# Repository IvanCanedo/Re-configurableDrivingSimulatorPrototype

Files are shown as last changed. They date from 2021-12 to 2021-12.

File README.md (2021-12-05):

# Re-configurableDrivingSimulatorPrototype
All files for a Re-configurable Driving Simulator Prototype

Requirements:

Windows 10 20H2

Solidworks Premium 2019 SP4.0

MATLAB 2018b 9.5.0.944444

LabVIEW 2019 19.0f2

KiCad 5.1.10

-To run MATLAB/Simulink simulation-

First open and run

/MATLAB/cinematica_inversa.m

then open and run:

/MATLAB/simulacion/platafomra_esfera.slx

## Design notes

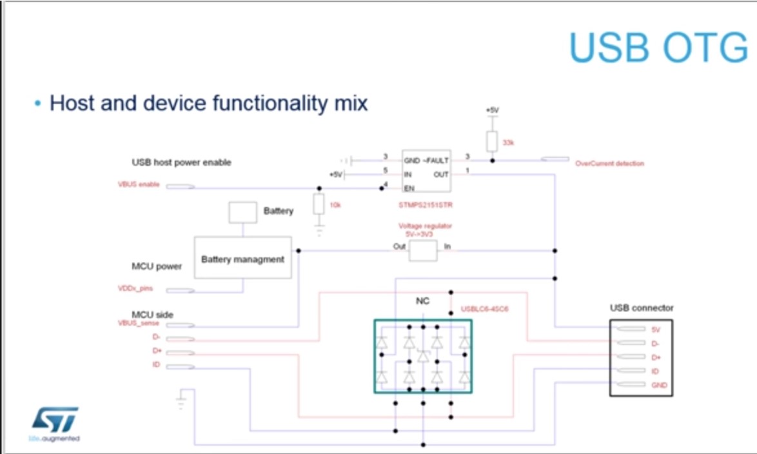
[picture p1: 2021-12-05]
KiCad/Nodo CAN/USB_OTG_ESD.jpg

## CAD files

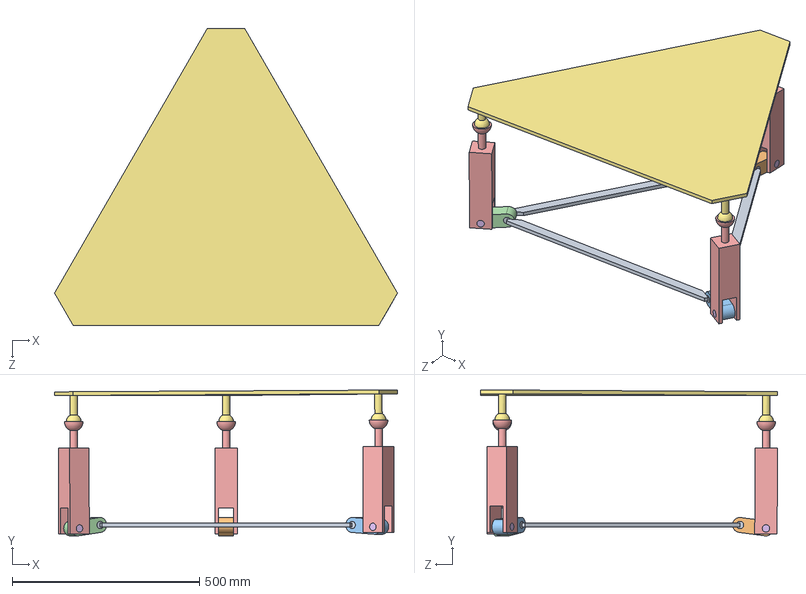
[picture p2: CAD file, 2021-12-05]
MATLAB/simulacion/platafomra_esfera.SLDASM
916.1 x 389.5 x 793.3 mm
base
viela
viela2
viela3
pilar x 3
pin inferior x 3
plataforma_soporte

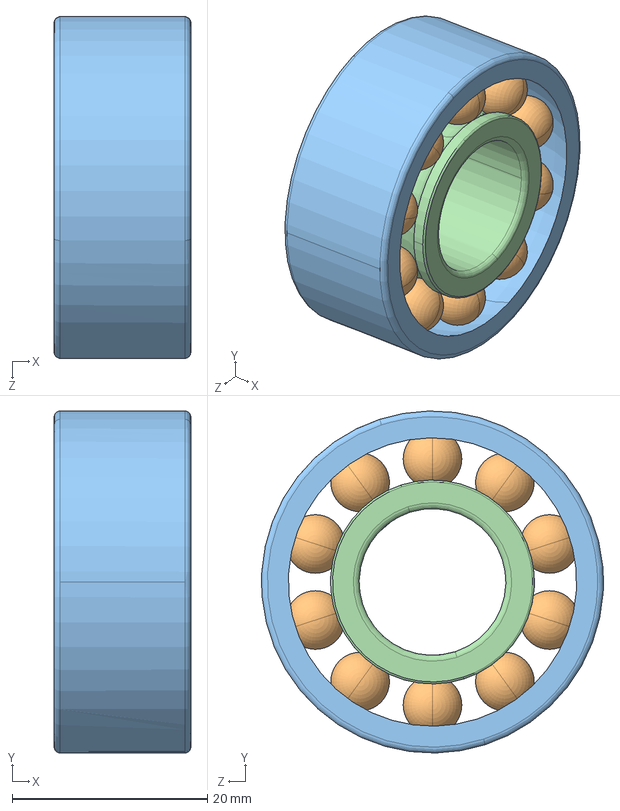
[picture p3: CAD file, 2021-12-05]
Solidworks/Full-Scale/PARTserver0202011032242190391701010e898ce/2202_ETN9.sldasm
14.0 x 35.0 x 35.0 mm
2202_ETN9_3 x 10
2202_ETN9_14 x 10
2202_ETN9_29
2202_ETN9_31

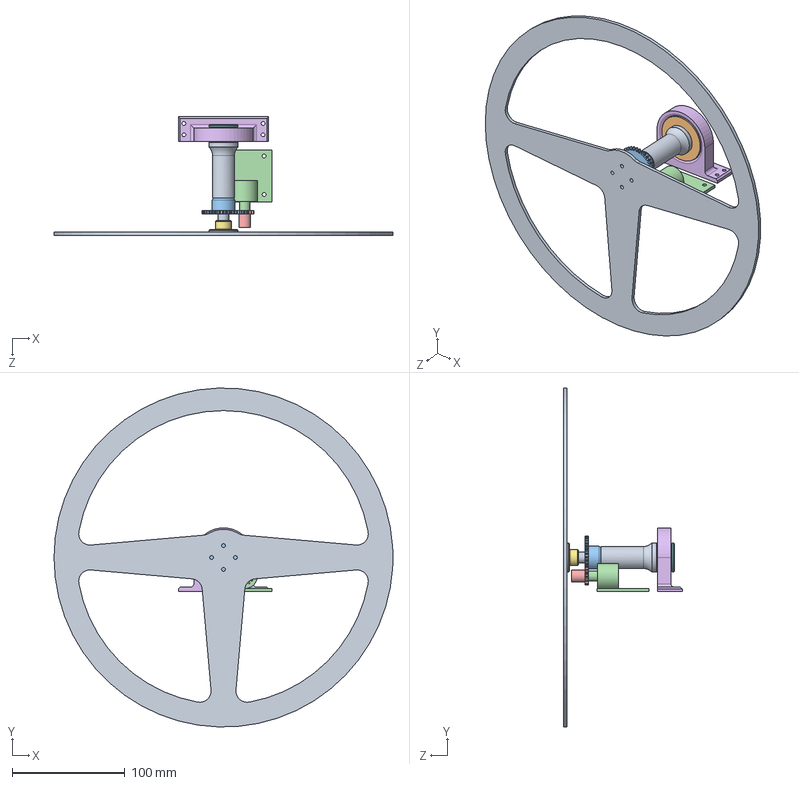
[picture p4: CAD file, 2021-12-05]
Solidworks/Vehicle control devices/volante.SLDASM
300.0 x 299.9 x 104.9 mm
eje
rodamiento
gear36
pot
gear14
abrazadera
cople volante
tapa rodamiento
SteeringWheel

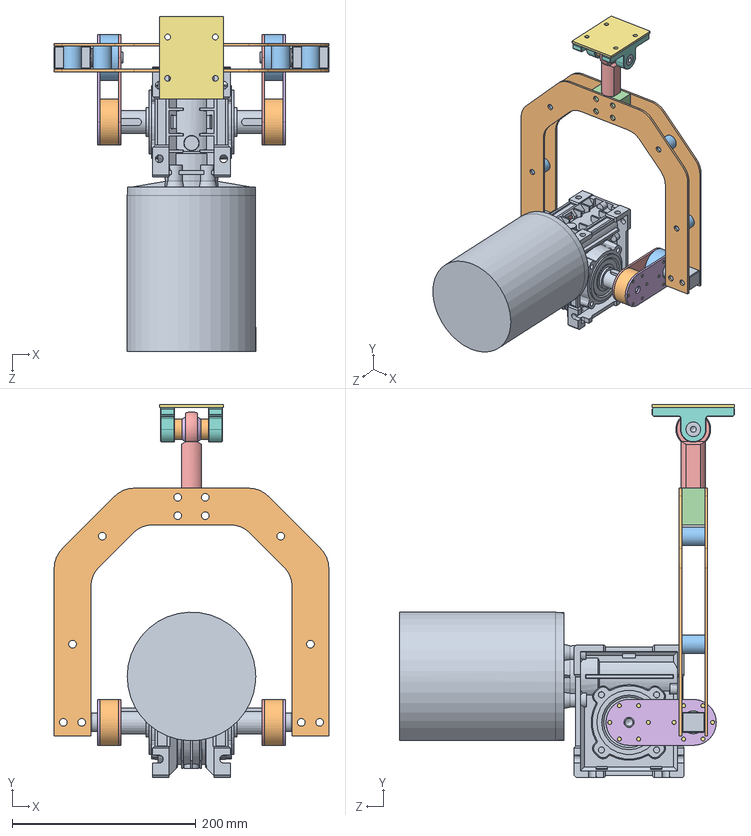
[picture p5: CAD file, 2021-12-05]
Solidworks/Full-Scale/motor con viela.SLDASM
299.0 x 406.0 x 365.0 mm
reductor con motor
cople flecha x 2
cople rodamiento x 2
rodameitno falso x 2
placa manivela x 2
placa manivela 2 x 2
tornillo falso x 24
anillo manivela x 2
pin de manivela x 2
arco x 2
virlo x 4
bloque
rotula
esfera
placa superior
soporte superior x 2
pin superior
virlo superior x 2

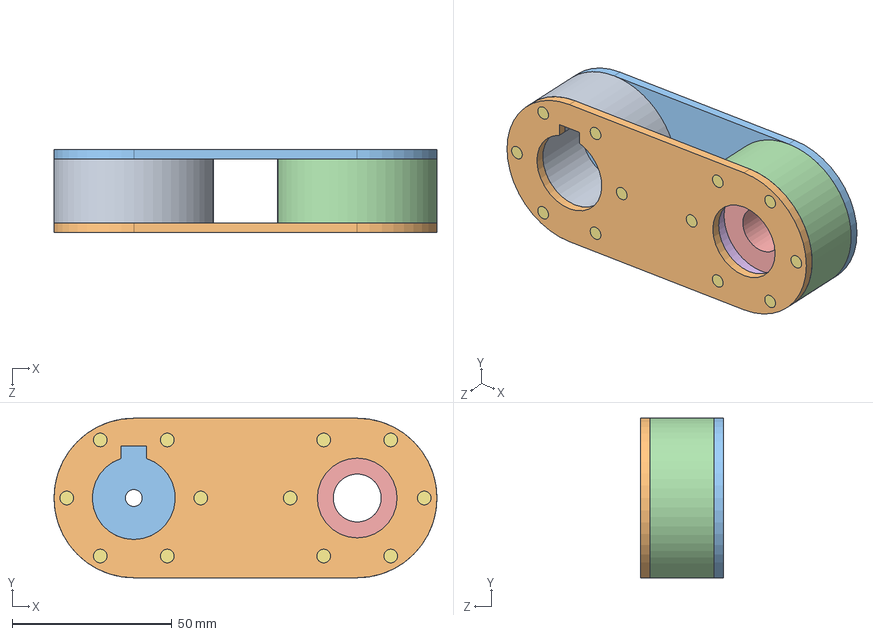
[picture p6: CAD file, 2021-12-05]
Solidworks/Finite Element/manivela 1.SLDASM
120.0 x 50.0 x 26.0 mm
cople flecha
placa manivela
placa manivela 2
cople rodamiento
rodameitno falso
anillo manivela
tornillo falso x 12

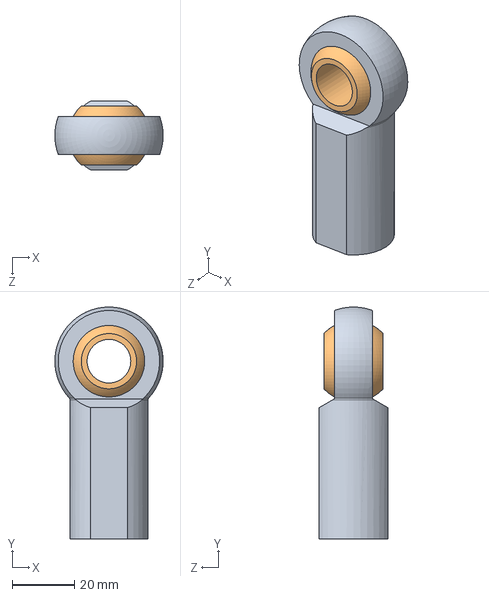
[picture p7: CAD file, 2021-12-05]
Solidworks/Full-Scale/Rotula de esfera.SLDASM
34.7 x 74.4 x 22.0 mm
rotula
esfera

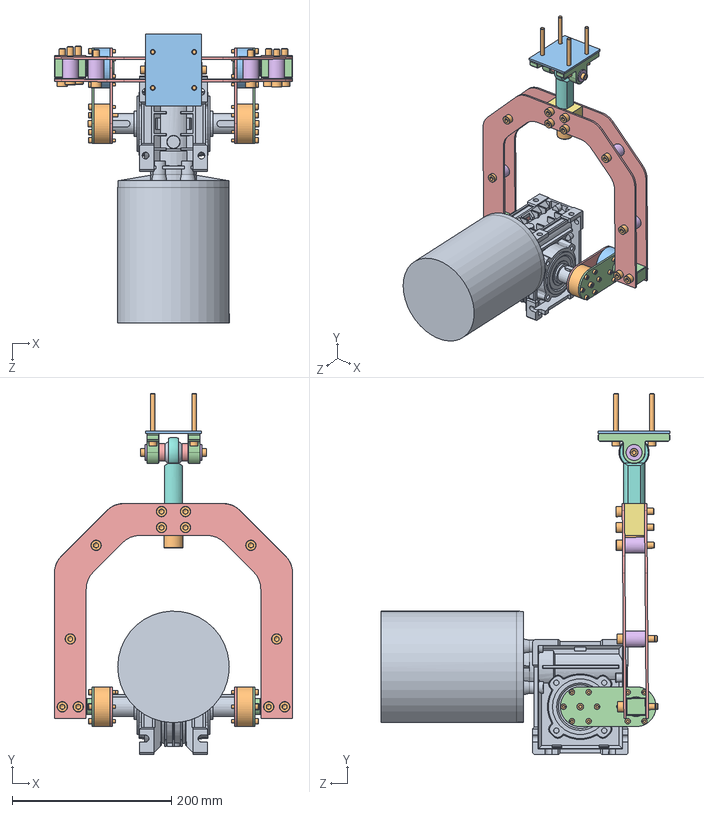
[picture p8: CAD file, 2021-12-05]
Solidworks/Full-Scale/pata con todo.SLDASM
299.0 x 453.0 x 362.5 mm
reductor con motor
cople flecha x 2
cople rodamiento x 2
placa manivela 2 x 2
placa manivela x 2
2202_ETN9_3 x 20
2202_ETN9_14 x 20
2202_ETN9_29 x 2
2202_ETN9_31 x 2
socket head cap screw_iso x 45
anillo manivela x 2
pin de manivela x 2
arco x 2
virlo x 4
bloque
rotula
esfera
pin superior
placa superior
soporte superior x 2
virlo superior x 2
plain washer 10669 type nl_iso x 2

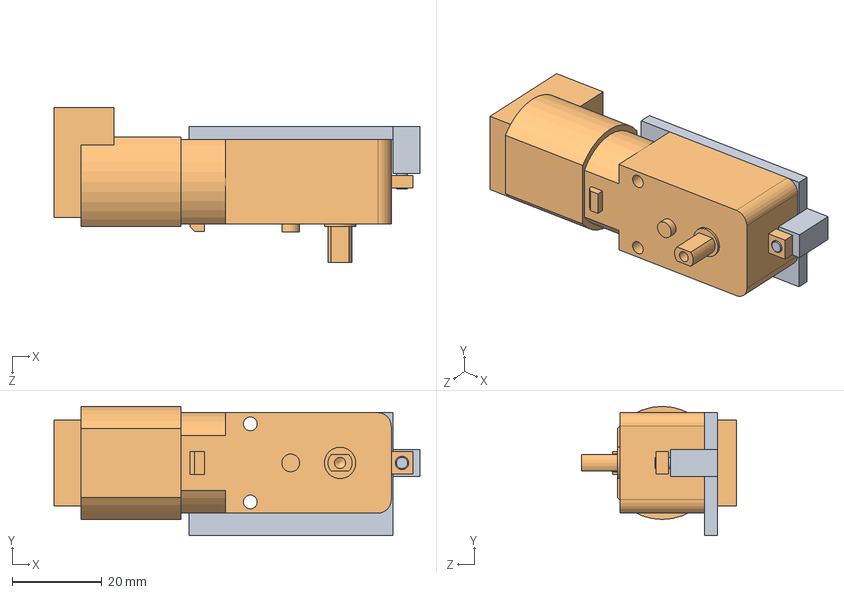
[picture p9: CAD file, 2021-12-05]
Solidworks/Scale/motor con base.SLDASM
81.6 x 28.8 x 34.6 mm
base motor
motor

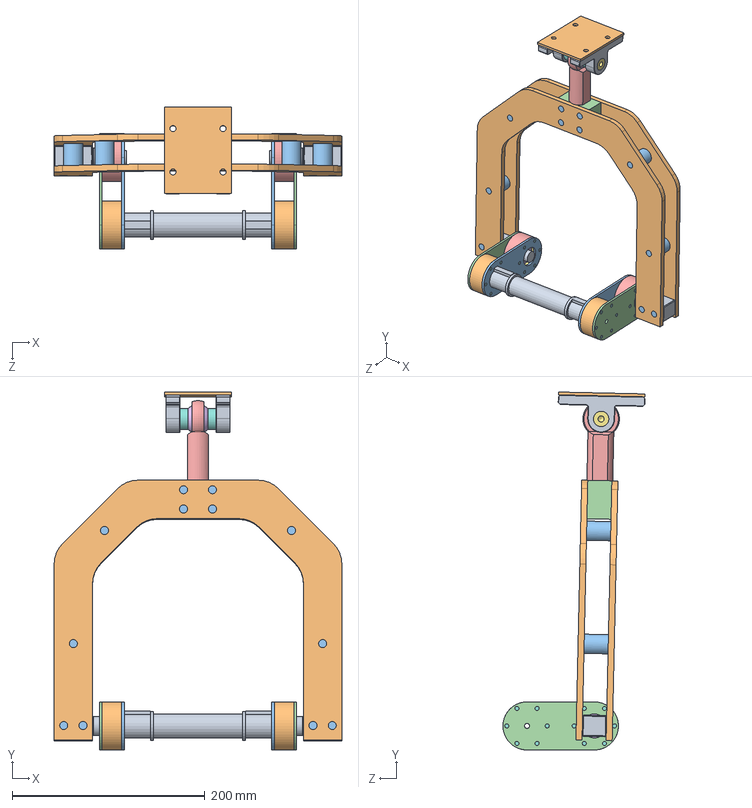
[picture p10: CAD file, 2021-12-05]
Solidworks/Finite Element/pata 1.SLDASM
299.0 x 371.9 x 147.6 mm
flecha motor
cople flecha x 2
placa manivela x 2
placa manivela 2 x 2
cople rodamiento x 2
rodameitno falso x 2
anillo manivela x 2
tornillo falso x 24
pin de manivela x 2
arco x 2
virlo x 4
bloque
rotula
esfera
pin superior
virlo superior x 2
soporte superior x 2
placa superior
tronillo falso m8 x 12

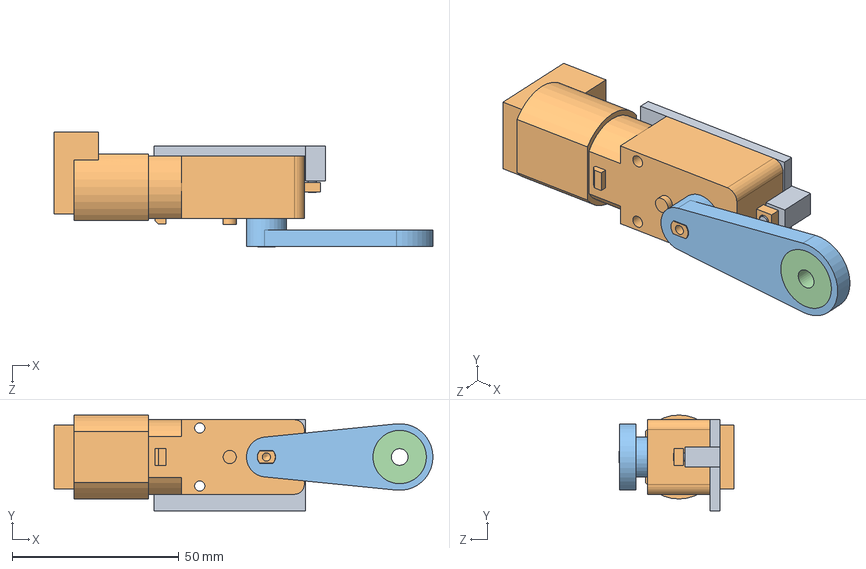
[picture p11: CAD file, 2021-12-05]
Solidworks/Scale/motor con base y manivela.SLDASM
113.7 x 28.8 x 34.6 mm
base motor
motor
manivela
rodamiento

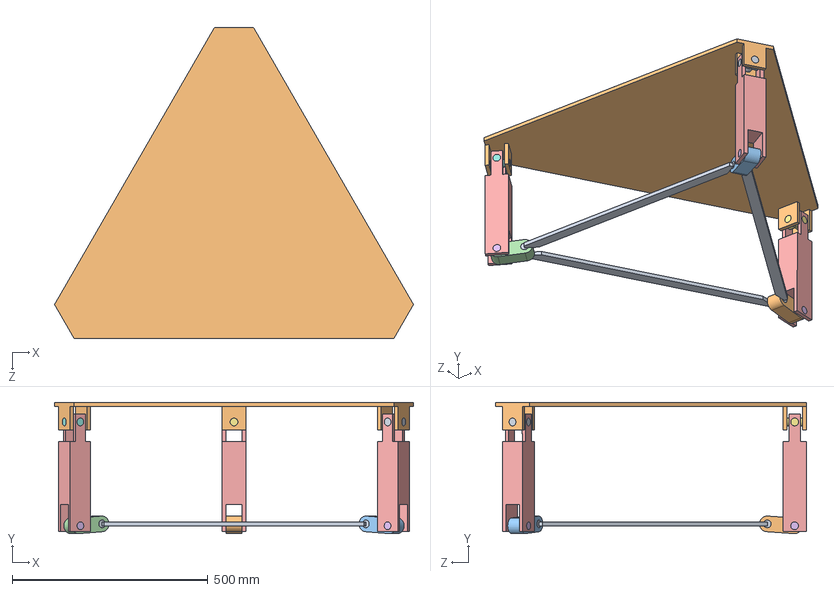
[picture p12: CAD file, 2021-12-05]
MATLAB/simulacion/base_viela.SLDASM
916.0 x 335.0 x 793.3 mm
base
viela
viela2
viela3
pilar x 3
pin inferior x 3
cruz
cruz2
cruz3
plataforma_soporte

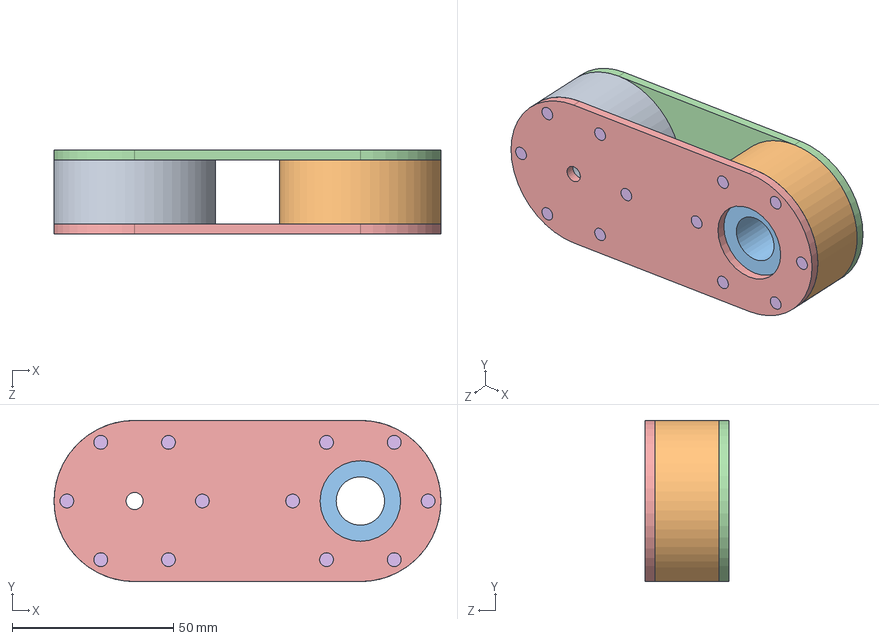
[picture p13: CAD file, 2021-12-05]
Solidworks/Full-Scale/manivela.SLDASM
120.0 x 50.0 x 26.0 mm
cople flecha
cople rodamiento
rodameitno falso
placa manivela
placa manivela 2
tornillo falso x 12
anillo manivela

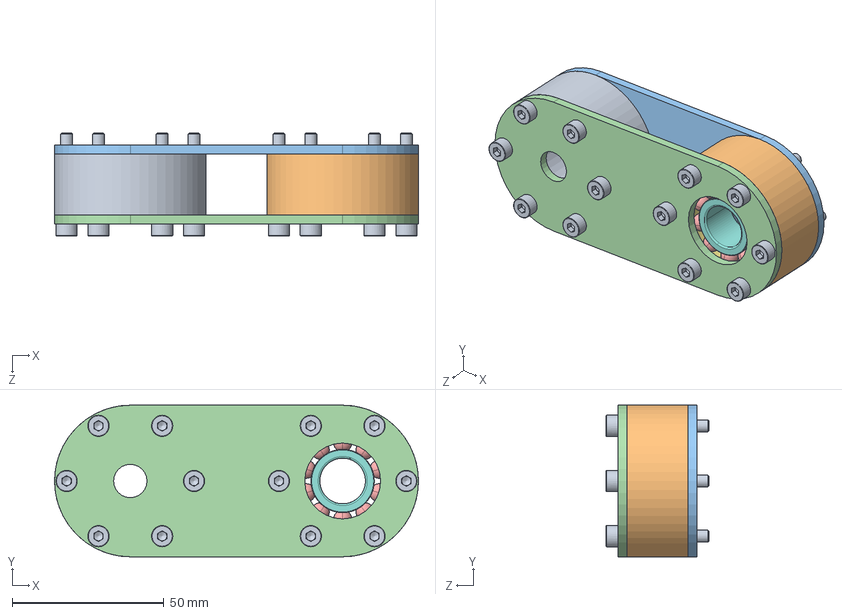
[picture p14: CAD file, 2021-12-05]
Solidworks/Full-Scale/manivela con rodamiento.SLDASM
120.0 x 50.0 x 34.0 mm
cople flecha
cople rodamiento
placa manivela
placa manivela 2
2202_ETN9_3 x 10
2202_ETN9_14 x 10
2202_ETN9_29
2202_ETN9_31
socket head cap screw_iso x 12
anillo manivela

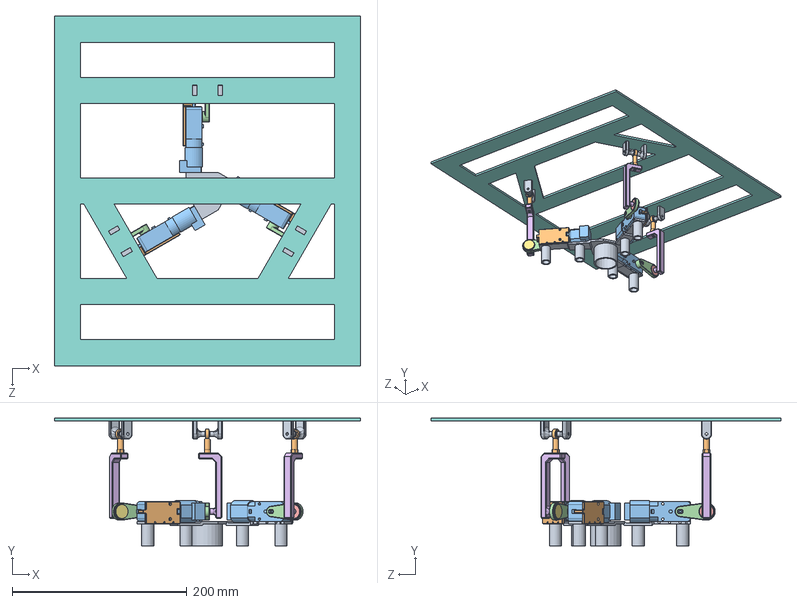
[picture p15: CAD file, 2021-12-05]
Solidworks/Scale/Plataforma.SLDASM
350.0 x 145.9 x 400.0 mm
base plataforma
base motor x 3
motor x 3
manivela x 3
rodamiento x 3
puente2 x 3
tapa rodamiento x 3
plataforma superior
soporte superior x 6
rotula de esfera x 3

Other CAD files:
Solidworks/Finite Element/manivela 2.SLDASM
Solidworks/Full-Scale/manivela derecha.SLDASM
Solidworks/Full-Scale/plataforma.SLDASM
Solidworks/Scale/Ensamblaje1.SLDASM
MATLAB/simulacion/base.SLDPRT
MATLAB/simulacion/base_Predeterminado_sldprt.STEP
MATLAB/simulacion/pilar.SLDPRT
MATLAB/simulacion/pilar_Predeterminado_sldprt.STEP
MATLAB/simulacion/pin inferior.SLDPRT
MATLAB/simulacion/pin inferior_Predeterminado_sldprt.STEP
MATLAB/simulacion/plataforma.SLDPRT
MATLAB/simulacion/plataforma_Predeterminado_sldprt.STEP
MATLAB/simulacion/plataforma_soporte.SLDPRT
MATLAB/simulacion/plataforma_soporte_Predeterminado_sldprt.STEP
MATLAB/simulacion/soporte sup.SLDPRT
MATLAB/simulacion/soporte sup_Predeterminado_sldprt.STEP
MATLAB/simulacion/viela.SLDPRT
MATLAB/simulacion/viela2.SLDPRT
MATLAB/simulacion/viela2_Predeterminado_sldprt.STEP
MATLAB/simulacion/viela3.SLDPRT
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

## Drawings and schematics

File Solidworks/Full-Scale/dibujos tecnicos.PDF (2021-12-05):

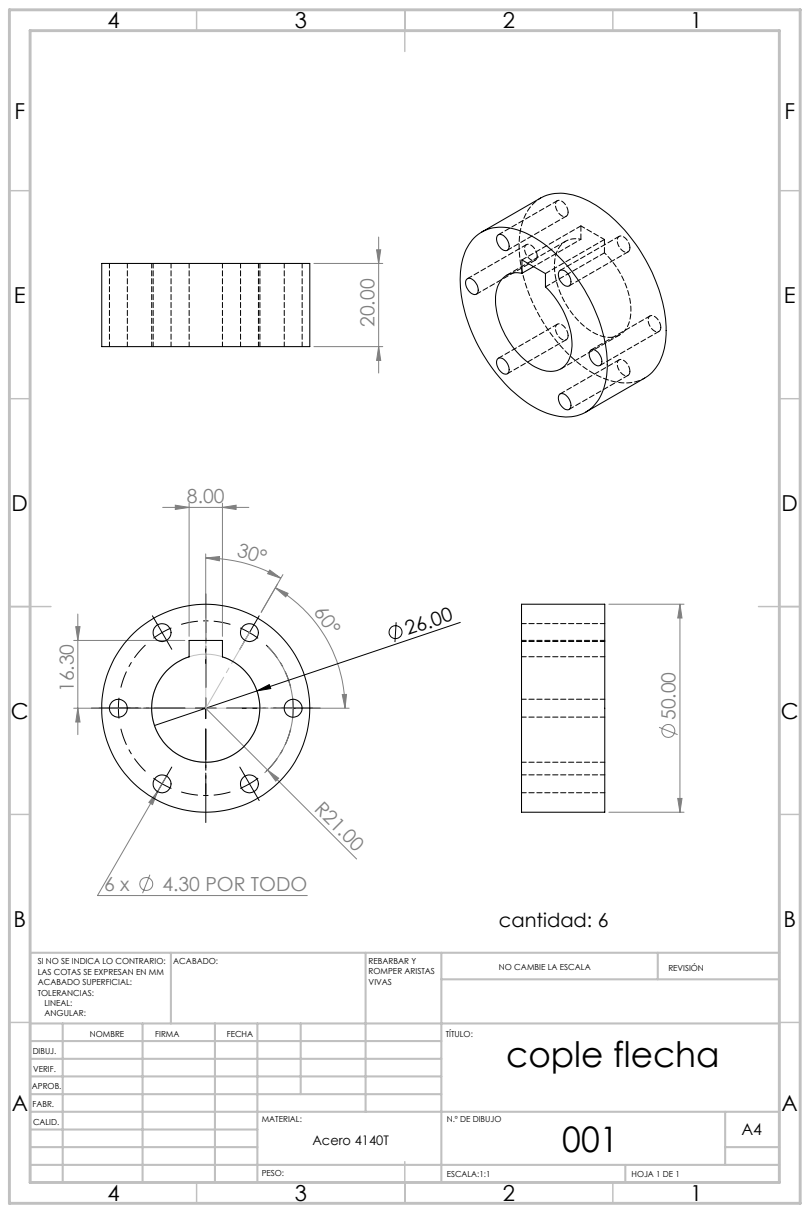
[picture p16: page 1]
4.30 POR TODO; ACABADO:; REBARBAR Y; ROMPER ARISTAS; NO CAMBIE LA ESCALA; REVISIÓN; ESCALA:1:1; HOJA 1 DE 1; cantidad: 6

SI NO SE INDICA LO CONTRARIO:
LAS COTAS SE EXPRESAN EN MM
ACABADO SUPERFICIAL:
TOLERANCIAS:
LINEAL:
ANGULAR:

NOMBRE | FIRMA | FECHA | | | | TÍTULO: cople flecha

DIBUJ.
VERIF.
APROB.
FABR.
CALID. | | | | MATERIAL: Acero 4140T | N.º DE DIBUJO | A4

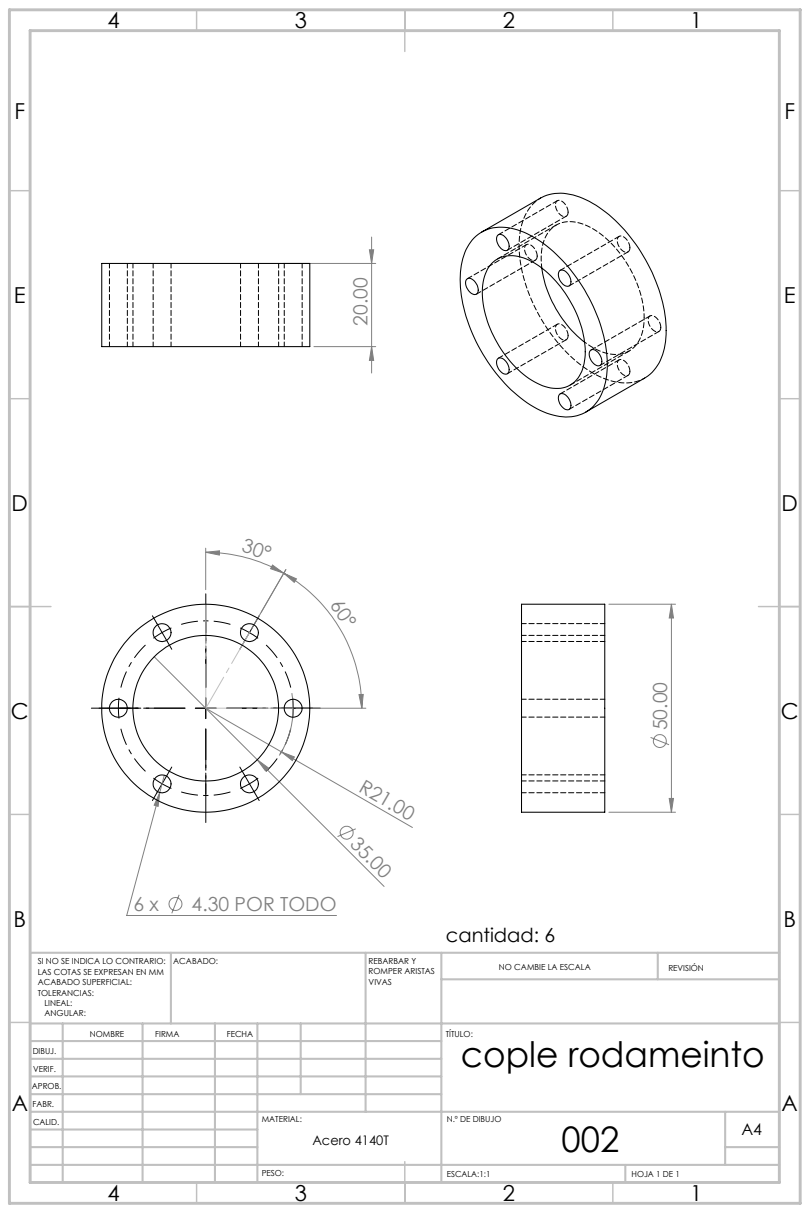
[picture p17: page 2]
4.30 POR TODO; ACABADO:; REBARBAR Y; ROMPER ARISTAS; NO CAMBIE LA ESCALA; REVISIÓN; cantidad: 6

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

NOMBRE | FIRMA | FECHA | TÍTULO: cople rodameinto

DIBUJ.
VERIF.
APROB.
FABR.

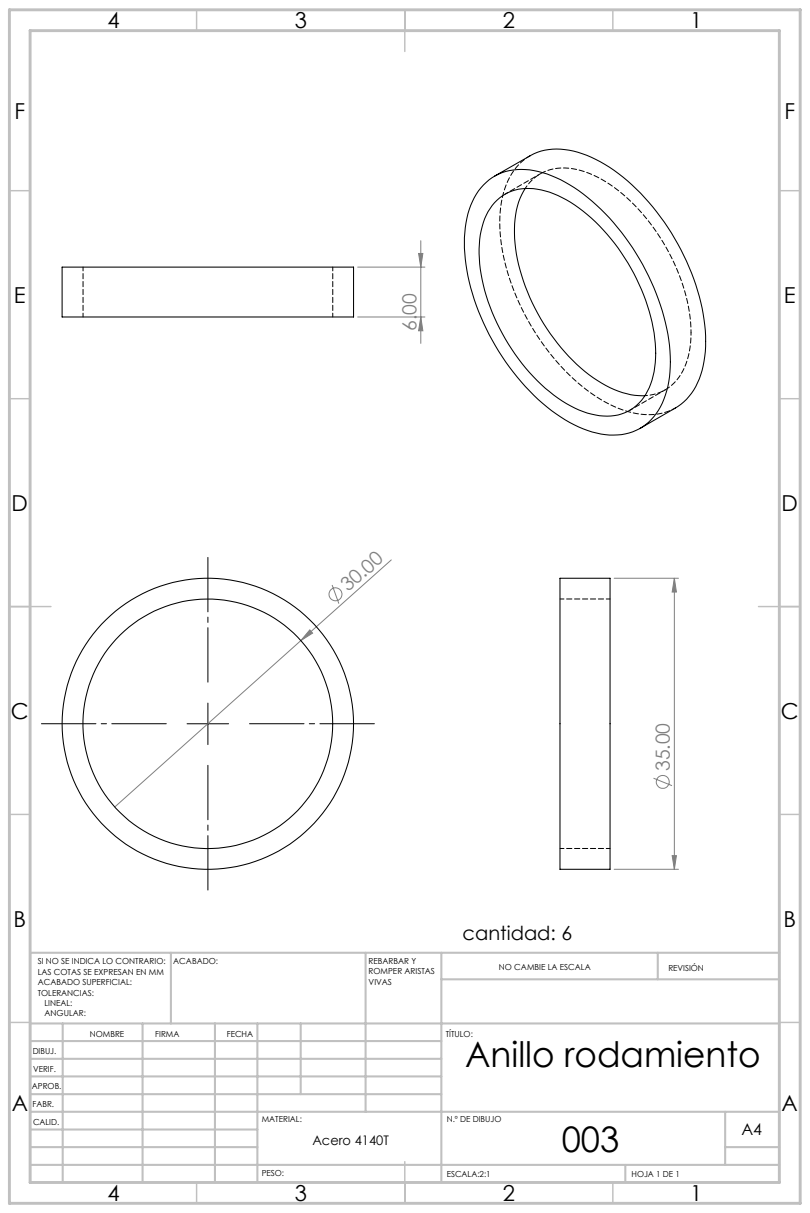
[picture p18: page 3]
cantidad: 6; ACABADO:; REBARBAR Y; ROMPER ARISTAS; NO CAMBIE LA ESCALA; REVISIÓN; ESCALA:2:1; HOJA 1 DE 1

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

NOMBRE | FIRMA | FECHA | TÍTULO: Anillo rodamiento

DIBUJ.
VERIF.
APROB.
FABR.

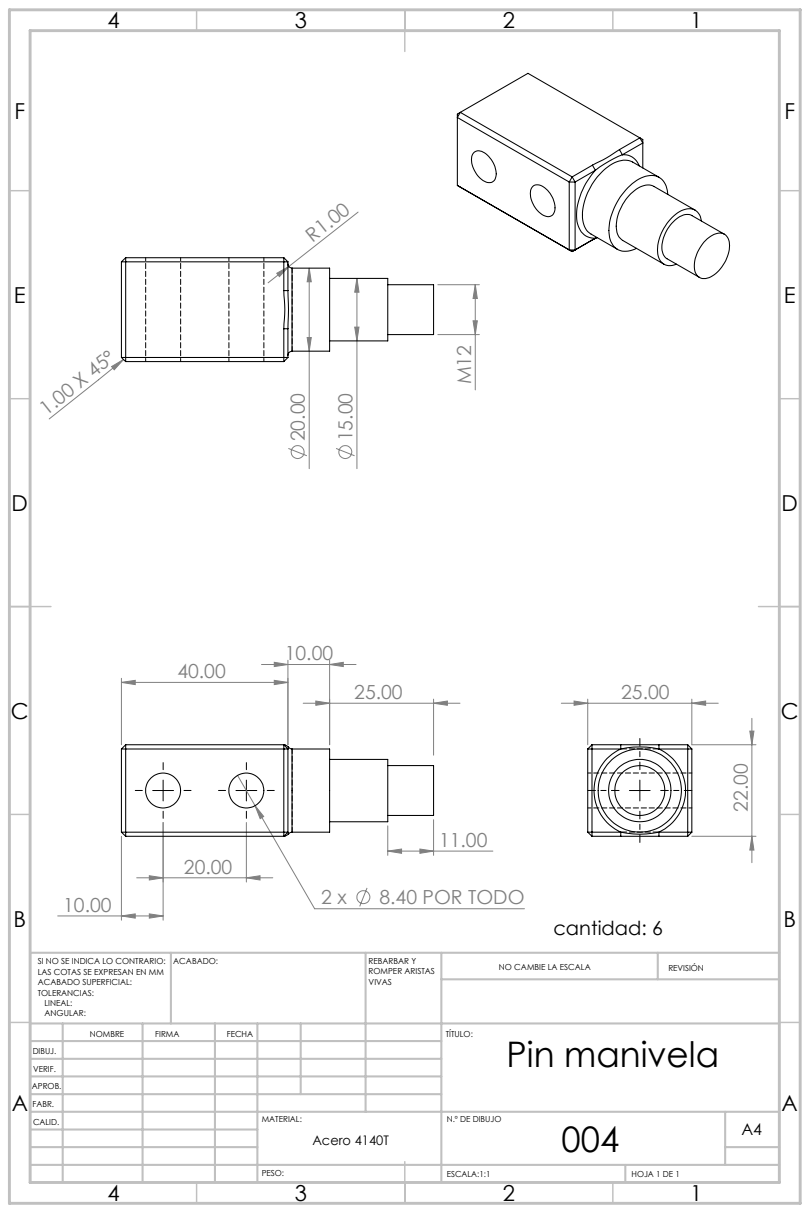
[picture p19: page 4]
8.40 POR TODO; cantidad: 6; ACABADO:; REBARBAR Y; ROMPER ARISTAS; NO CAMBIE LA ESCALA; REVISIÓN

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

NOMBRE | FIRMA | FECHA | TÍTULO: Pin manivela

DIBUJ.
VERIF.
APROB.
FABR.

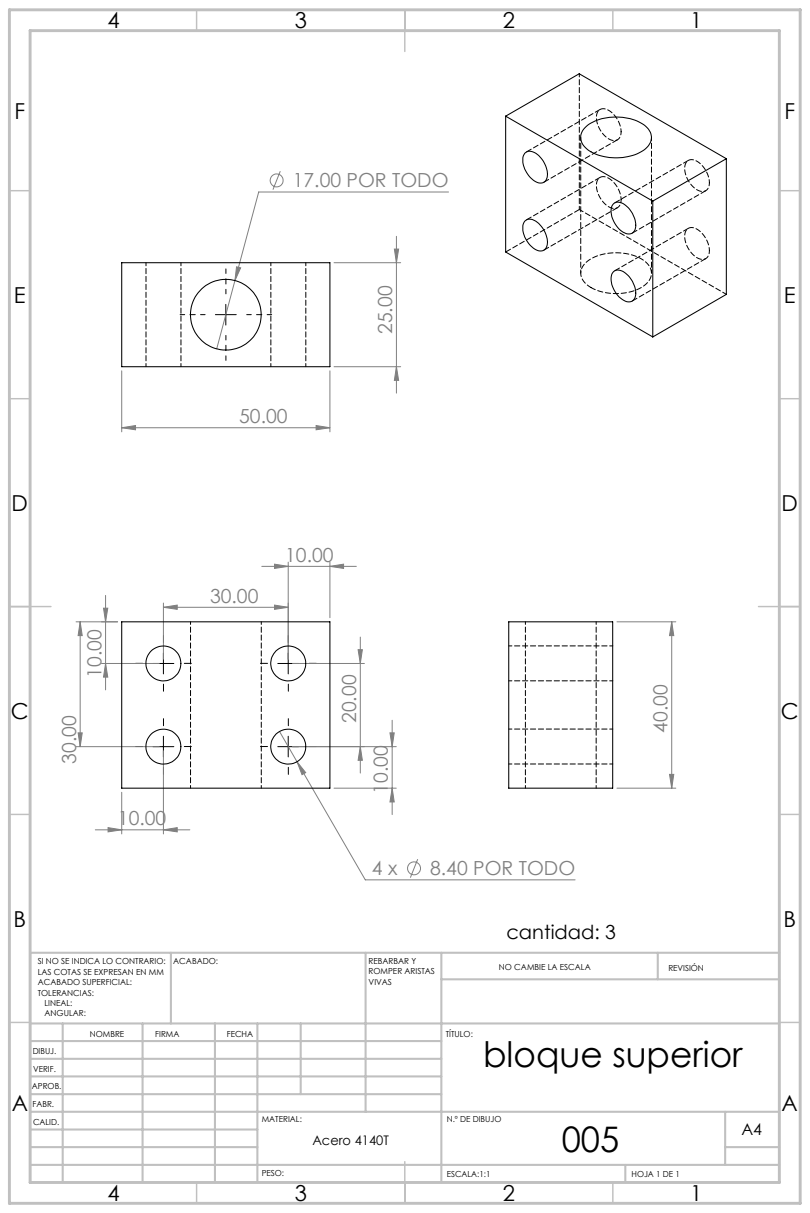
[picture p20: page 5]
8.40 POR TODO 10.00; 17.00 POR TODO 25.00; cantidad: 3; ACABADO:; REBARBAR Y; ROMPER ARISTAS; NO CAMBIE LA ESCALA; REVISIÓN

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

NOMBRE | FIRMA | FECHA | TÍTULO: bloque superior

DIBUJ.
VERIF.
APROB.
FABR.

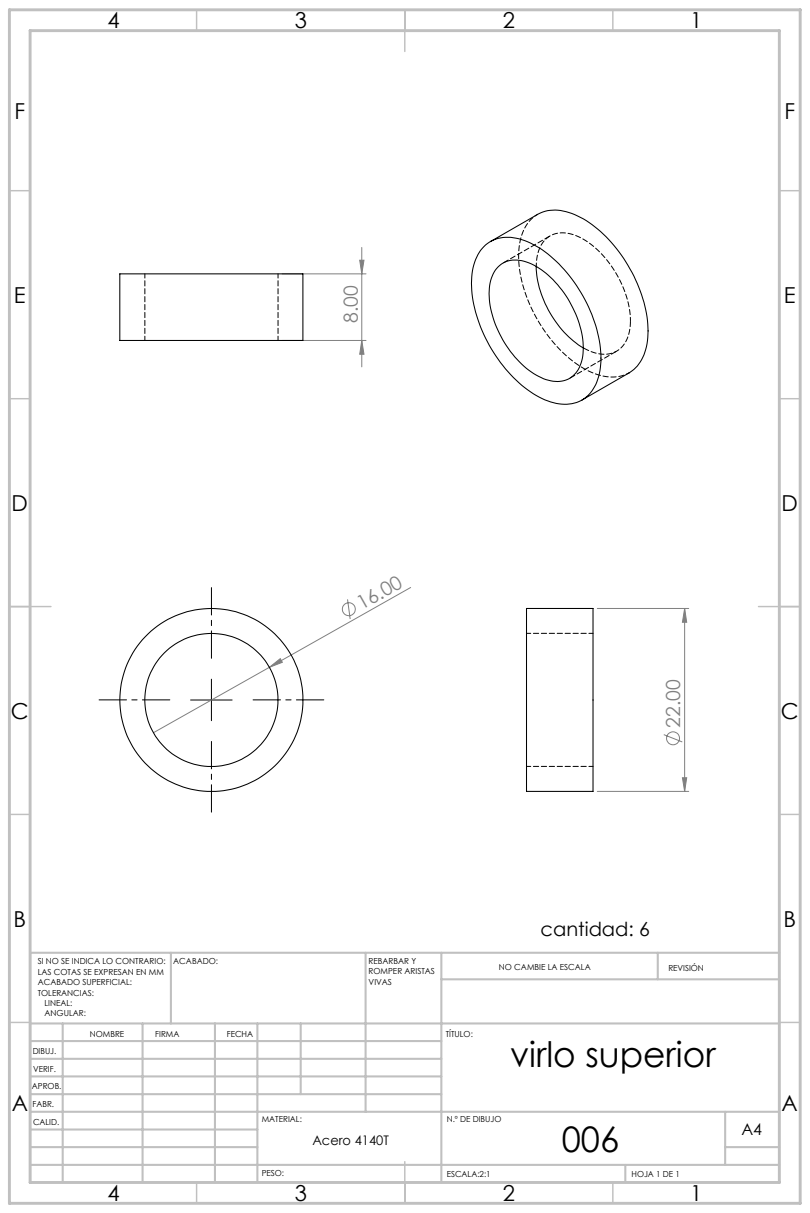
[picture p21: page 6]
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

NOMBRE | FIRMA | FECHA | TÍTULO: virlo superior

DIBUJ.
VERIF.
APROB.
FABR.

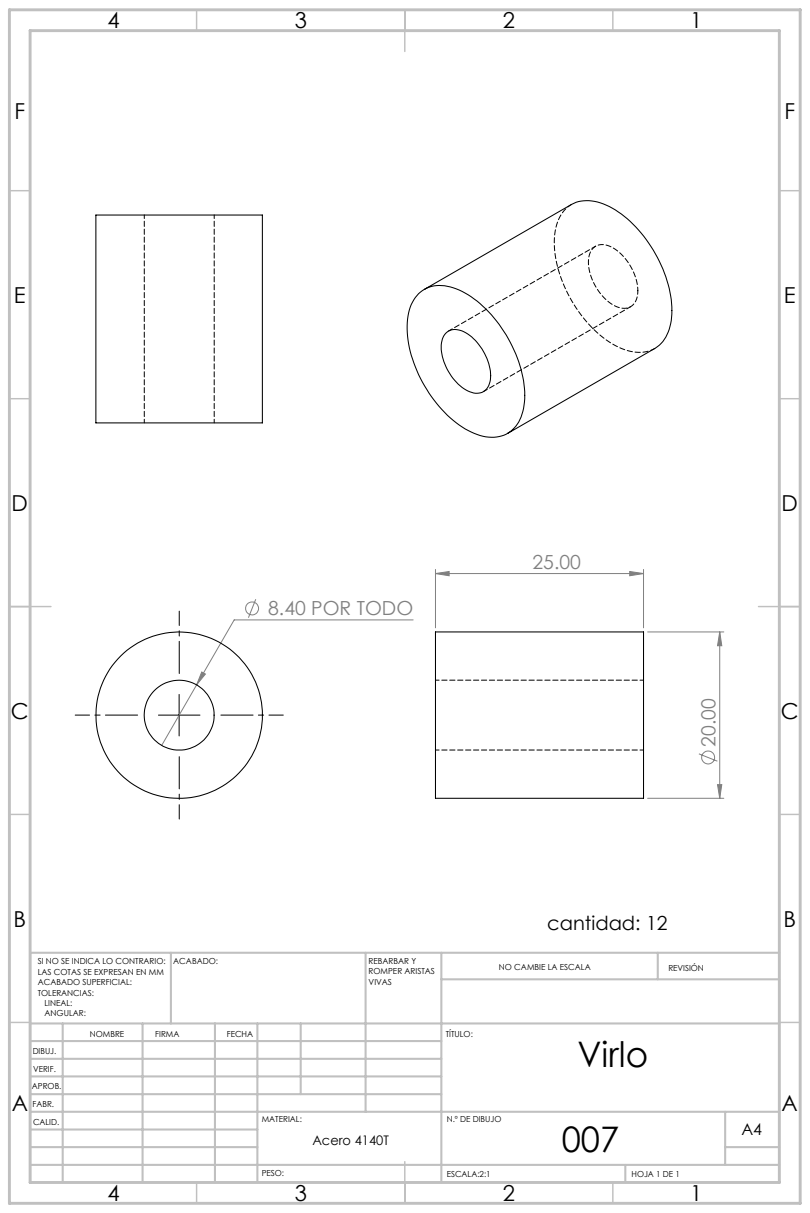
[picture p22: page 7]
8.40 POR TODO; cantidad: 12; ACABADO:; REBARBAR Y; ROMPER ARISTAS; NO CAMBIE LA ESCALA; REVISIÓN; ESCALA:2:1; HOJA 1 DE 1

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

NOMBRE | FIRMA | FECHA | TÍTULO: Virlo

DIBUJ.
VERIF.
APROB.
FABR.

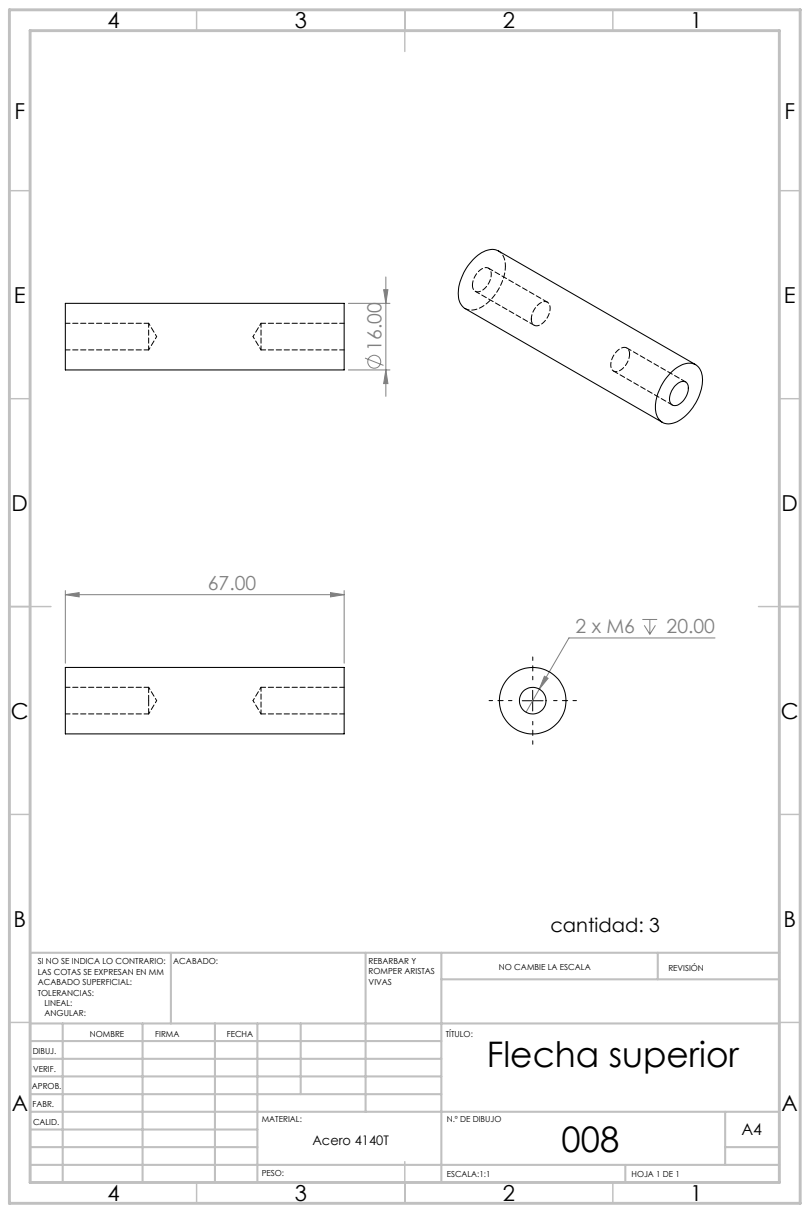
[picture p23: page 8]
cantidad: 3; ACABADO:; REBARBAR Y; ROMPER ARISTAS; NO CAMBIE LA ESCALA; REVISIÓN

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

NOMBRE | FIRMA | FECHA | TÍTULO: Flecha superior

DIBUJ.
VERIF.
APROB.
FABR.

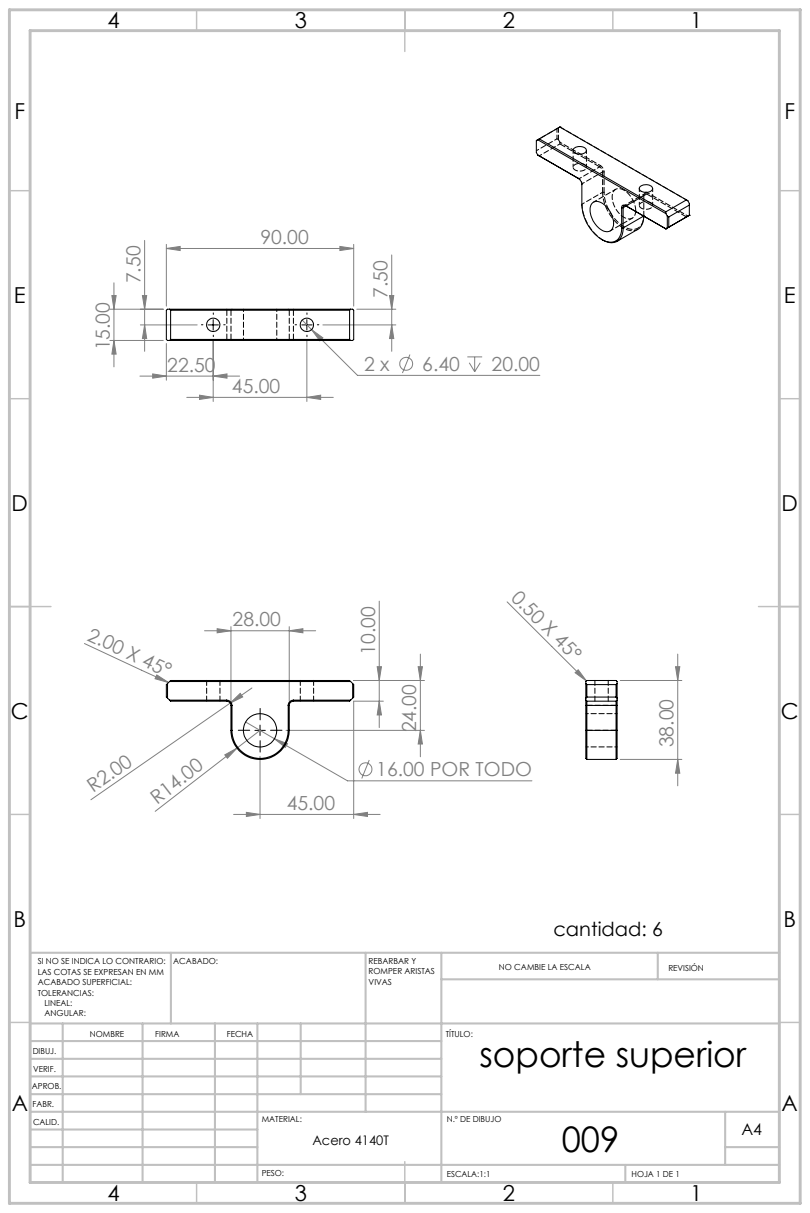
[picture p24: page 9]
16.00 POR TODO; cantidad: 6; ACABADO:; REBARBAR Y; ROMPER ARISTAS; NO CAMBIE LA ESCALA; REVISIÓN

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

NOMBRE | FIRMA | FECHA | TÍTULO: soporte superior

DIBUJ.
VERIF.
APROB.
FABR.

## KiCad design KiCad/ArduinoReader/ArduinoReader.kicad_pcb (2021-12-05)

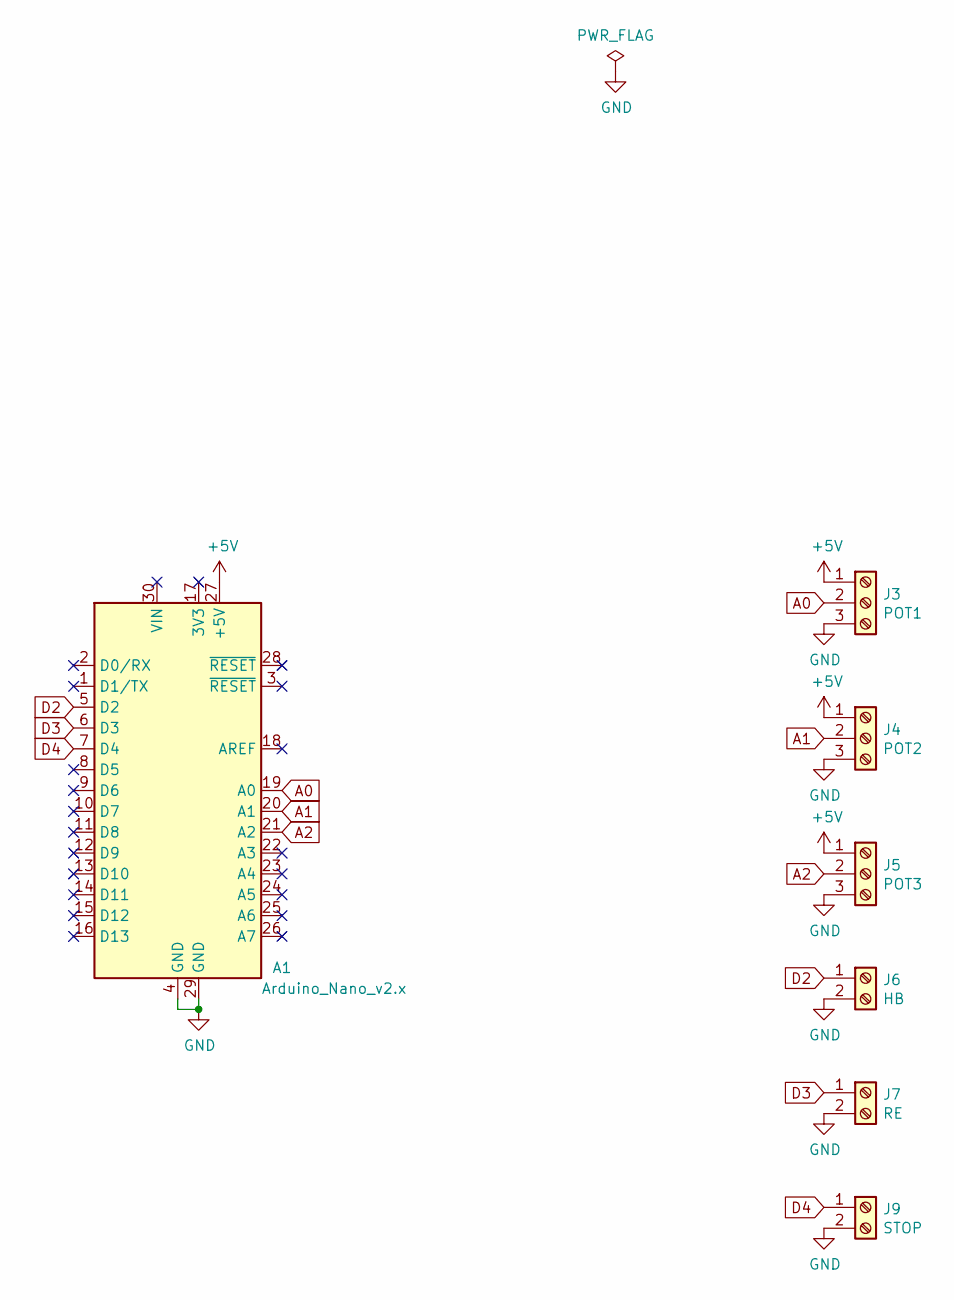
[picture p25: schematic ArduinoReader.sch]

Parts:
A1: Arduino_Nano_v2.x; Arduino_Nano
J3: POT1; TerminalBlock_Phoenix_MKDS-1,5-3_1x03_P5.00mm_Horizontal
J4: POT2; TerminalBlock_Phoenix_MKDS-1,5-3_1x03_P5.00mm_Horizontal
J5: POT3; TerminalBlock_Phoenix_MKDS-1,5-3_1x03_P5.00mm_Horizontal
J6: HB; TerminalBlock_Phoenix_MKDS-1,5-2_1x02_P5.00mm_Horizontal
J7: RE; TerminalBlock_Phoenix_MKDS-1,5-2_1x02_P5.00mm_Horizontal
J9: STOP; TerminalBlock_Phoenix_MKDS-1,5-2_1x02_P5.00mm_Horizontal

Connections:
+5V: A1.27 (+5V), J3.1, J4.1, J5.1
A0: A1.19 (A0), J3.2
A1: A1.20 (A1), J4.2
A2: A1.21 (A2), J5.2
D2: A1.5 (D2), J6.1
D3: A1.6 (D3), J7.1
D4: A1.7 (D4), J9.1
GND: A1.4 (GND), A1.29 (GND), J3.3, J4.3, J5.3, J6.2, J7.2, J9.2

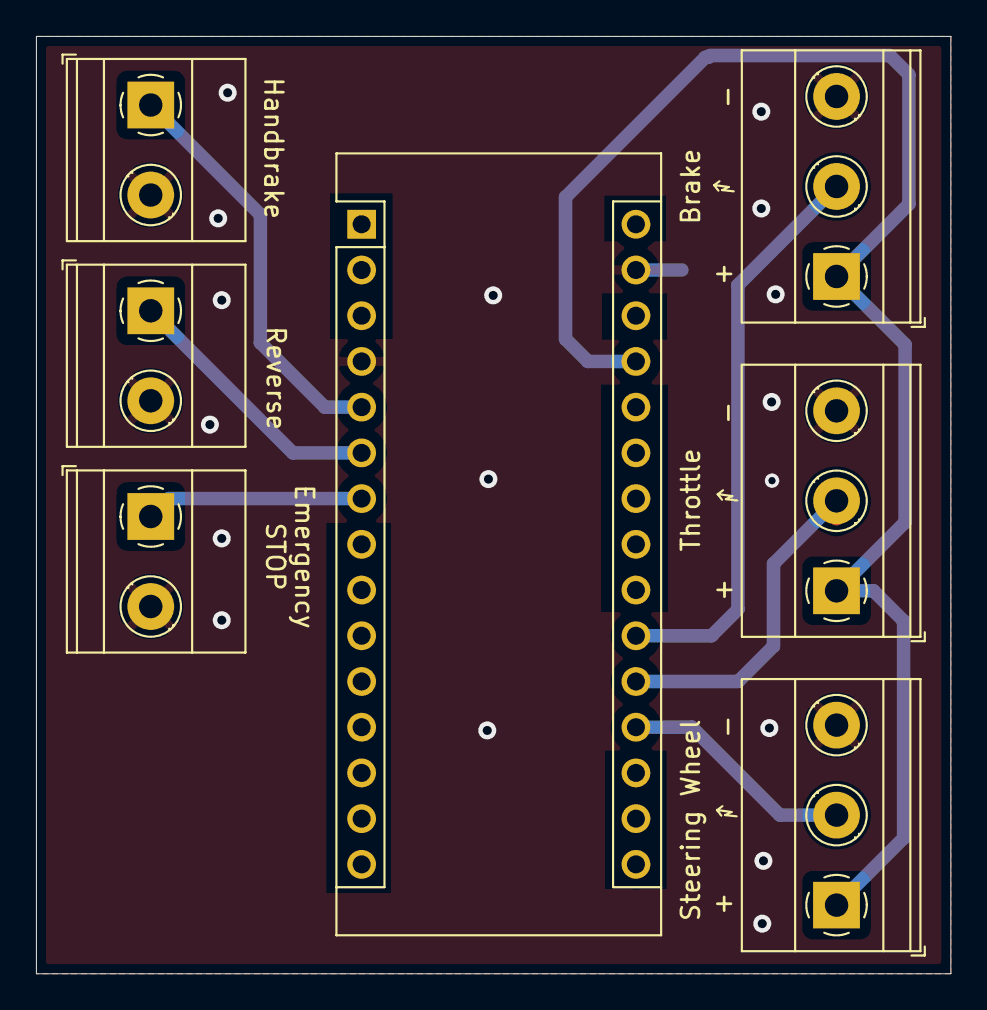
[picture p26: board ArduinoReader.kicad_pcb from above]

Board: 2 copper layers, 50.8 x 52.1 mm, 7 parts (0 on the bottom side), 8 nets.

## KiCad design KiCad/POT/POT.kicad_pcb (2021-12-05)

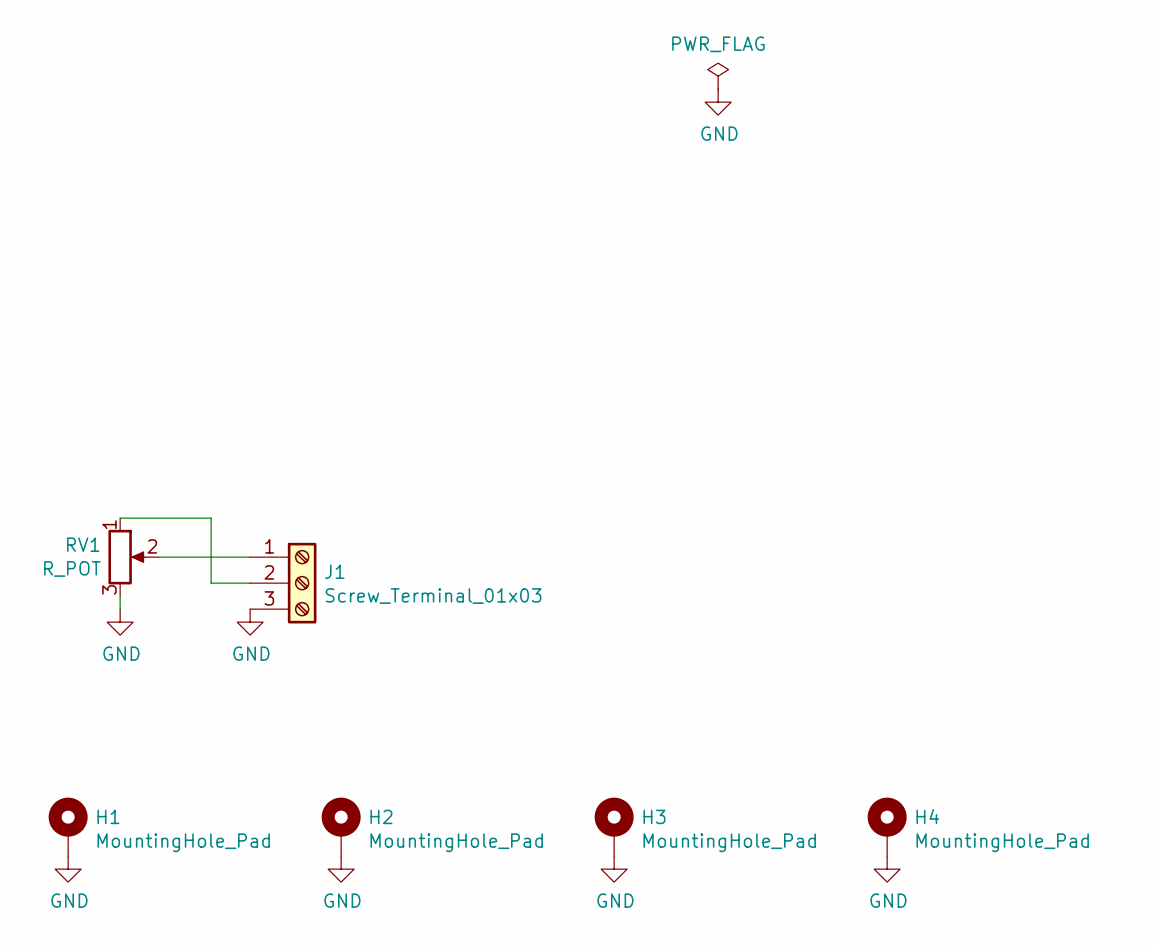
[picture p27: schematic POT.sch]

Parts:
H1, H2, H3, H4: MountingHole_Pad; MountingHole_3.2mm_M3_Pad_Via
J1: Screw_Terminal_01x03; TerminalBlock_Phoenix_MKDS-1,5-3-5.08_1x03_P5.08mm_Horizont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
RV1: R_POT; POT3600

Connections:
GND: H1.1, H2.1, H3.1, H4.1, J1.3, RV1.3
unnamed: J1.1, RV1.2
unnamed: J1.2, RV1.1

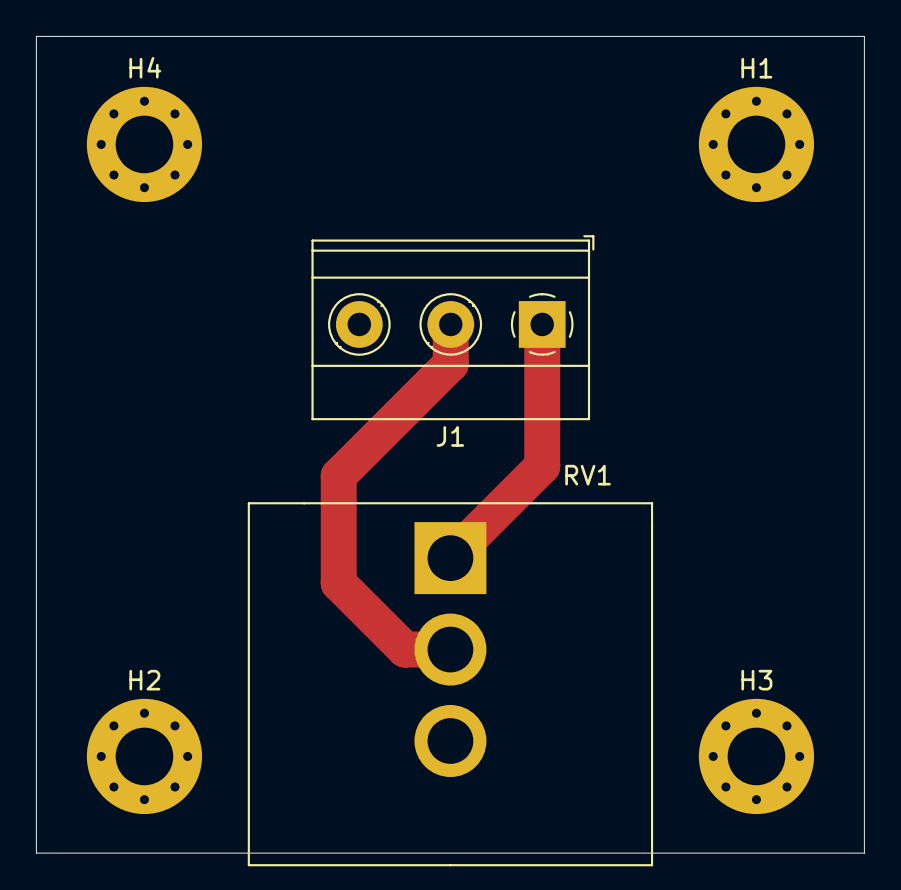
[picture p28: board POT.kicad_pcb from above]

Board: 2 copper layers, 46.0 x 45.4 mm, 6 parts (0 on the bottom side), 3 nets.

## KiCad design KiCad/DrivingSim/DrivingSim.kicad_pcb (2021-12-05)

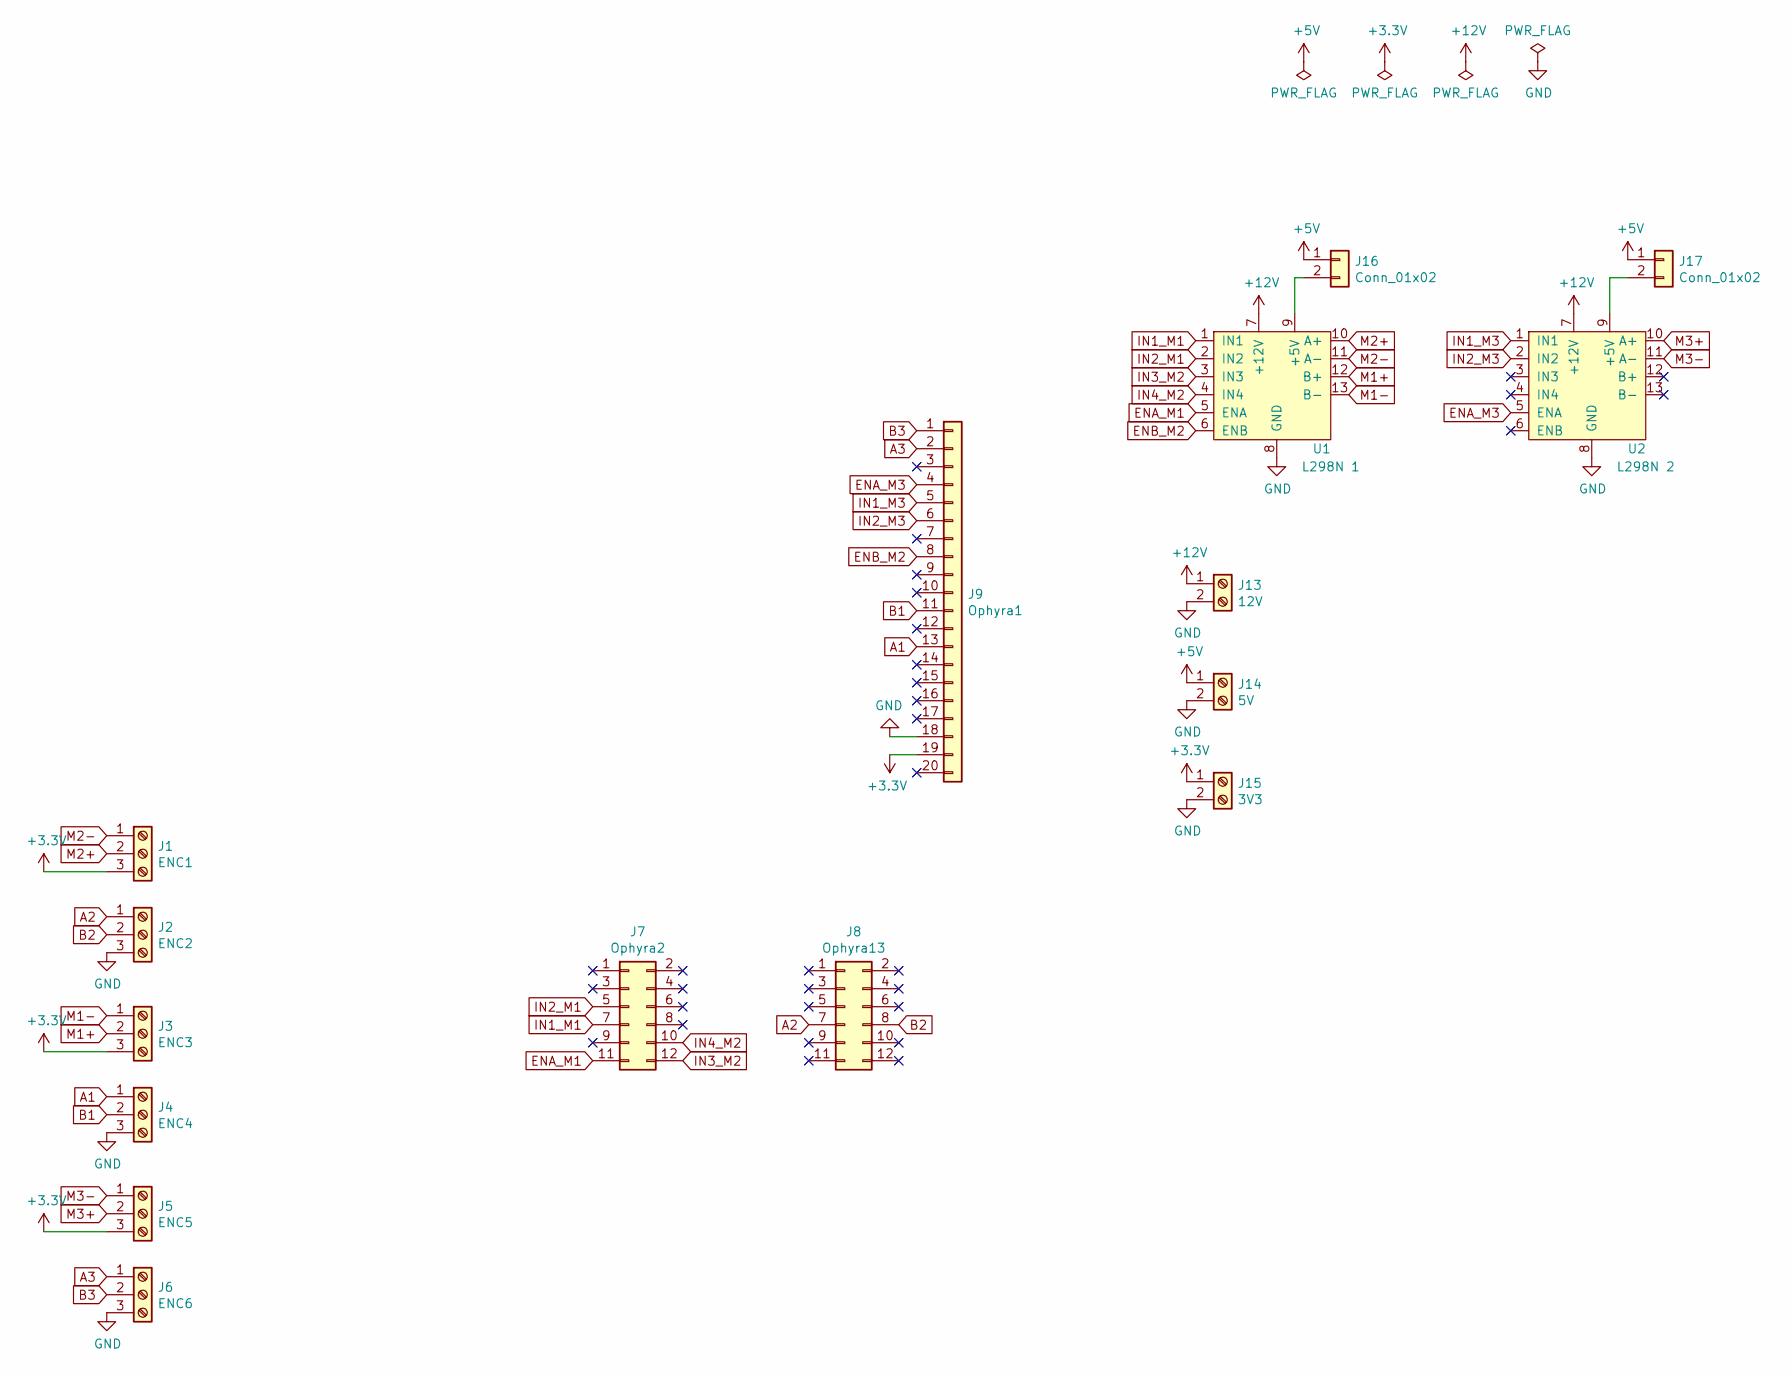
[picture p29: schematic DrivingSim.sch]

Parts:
J1: ENC1; TerminalBlock_Phoenix_MKDS-1,5-3-5.08_1x03_P5.08mm_Horizont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
J2: ENC2; TerminalBlock_Phoenix_MKDS-1,5-3-5.08_1x03_P5.08mm_Horizont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
J3: ENC3; TerminalBlock_Phoenix_MKDS-1,5-3-5.08_1x03_P5.08mm_Horizont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
J4: ENC4; TerminalBlock_Phoenix_MKDS-1,5-3-5.08_1x03_P5.08mm_Horizont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
J5: ENC5; TerminalBlock_Phoenix_MKDS-1,5-3-5.08_1x03_P5.08mm_Horizont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
J6: ENC6; TerminalBlock_Phoenix_MKDS-1,5-3-5.08_1x03_P5.08mm_Horizont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
J7: Ophyra2; PinHeader_2x06_P2.54mm_Vertical
J8: Ophyra13; PinHeader_2x06_P2.54mm_Vertical
J9: Ophyra1; PinSocket_1x20_P2.54mm_Vertical
J13: 12V; TerminalBlock_Phoenix_MKDS-1,5-2-5.08_1x02_P5.08mm_Horizont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
J14: 5V; TerminalBlock_Phoenix_MKDS-1,5-2-5.08_1x02_P5.08mm_Horizont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
J15: 3V3; TerminalBlock_Phoenix_MKDS-1,5-2-5.08_1x02_P5.08mm_Horizont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
J16, J17: Conn_01x02; PinHeader_1x02_P2.54mm_Vertical
U1: L298N 1; L298N
U2: L298N 2; L298N

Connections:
+3V3: J1.3, J3.3, J5.3, J9.19, J15.1
+5V: J14.1, J16.1, J17.1
+12V: J13.1, U1.7 (+12V), U2.7 (+12V)
A1: J4.1, J9.13
A2: J2.1, J8.7
A3: J6.1, J9.2
B1: J4.2, J9.11
B2: J2.2, J8.8
B3: J6.2, J9.1
ENA_M1: J7.11, U1.5 (ENA)
ENA_M3: J9.4, U2.5 (ENA)
ENB_M2: J9.8, U1.6 (ENB)
GND: J2.3, J4.3, J6.3, J9.18, J13.2, J14.2, J15.2, U1.8 (GND), U2.8 (GND)
IN1_M1: J7.7, U1.1 (IN1)
IN1_M3: J9.5, U2.1 (IN1)
IN2_M1: J7.5, U1.2 (IN2)
IN2_M3: J9.6, U2.2 (IN2)
IN3_M2: J7.12, U1.3 (IN3)
IN4_M2: J7.10, U1.4 (IN4)
M1+: J3.2, U1.12 (B+)
M1-: J3.1, U1.13 (B-)
M2+: J1.2, U1.10 (A+)
M2-: J1.1, U1.11 (A-)
M3+: J5.2, U2.10 (A+)
M3-: J5.1, U2.11 (A-)
unnamed: J16.2, U1.9 (+5V)
unnamed: J17.2, U2.9 (+5V)

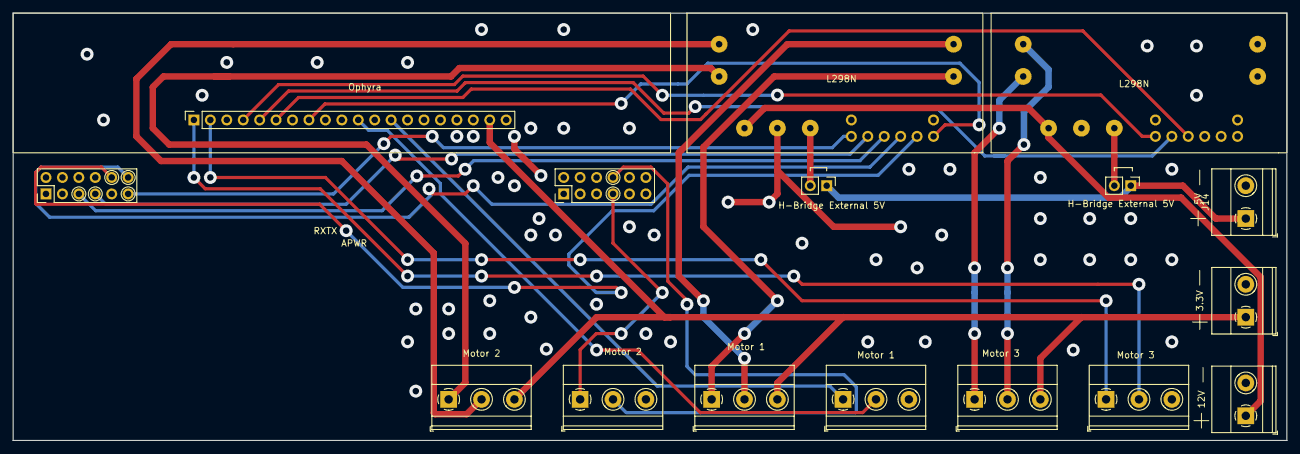
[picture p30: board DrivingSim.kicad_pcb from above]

Board: 2 copper layers, 196.9 x 66.0 mm, 16 parts (0 on the bottom side), 27 nets.

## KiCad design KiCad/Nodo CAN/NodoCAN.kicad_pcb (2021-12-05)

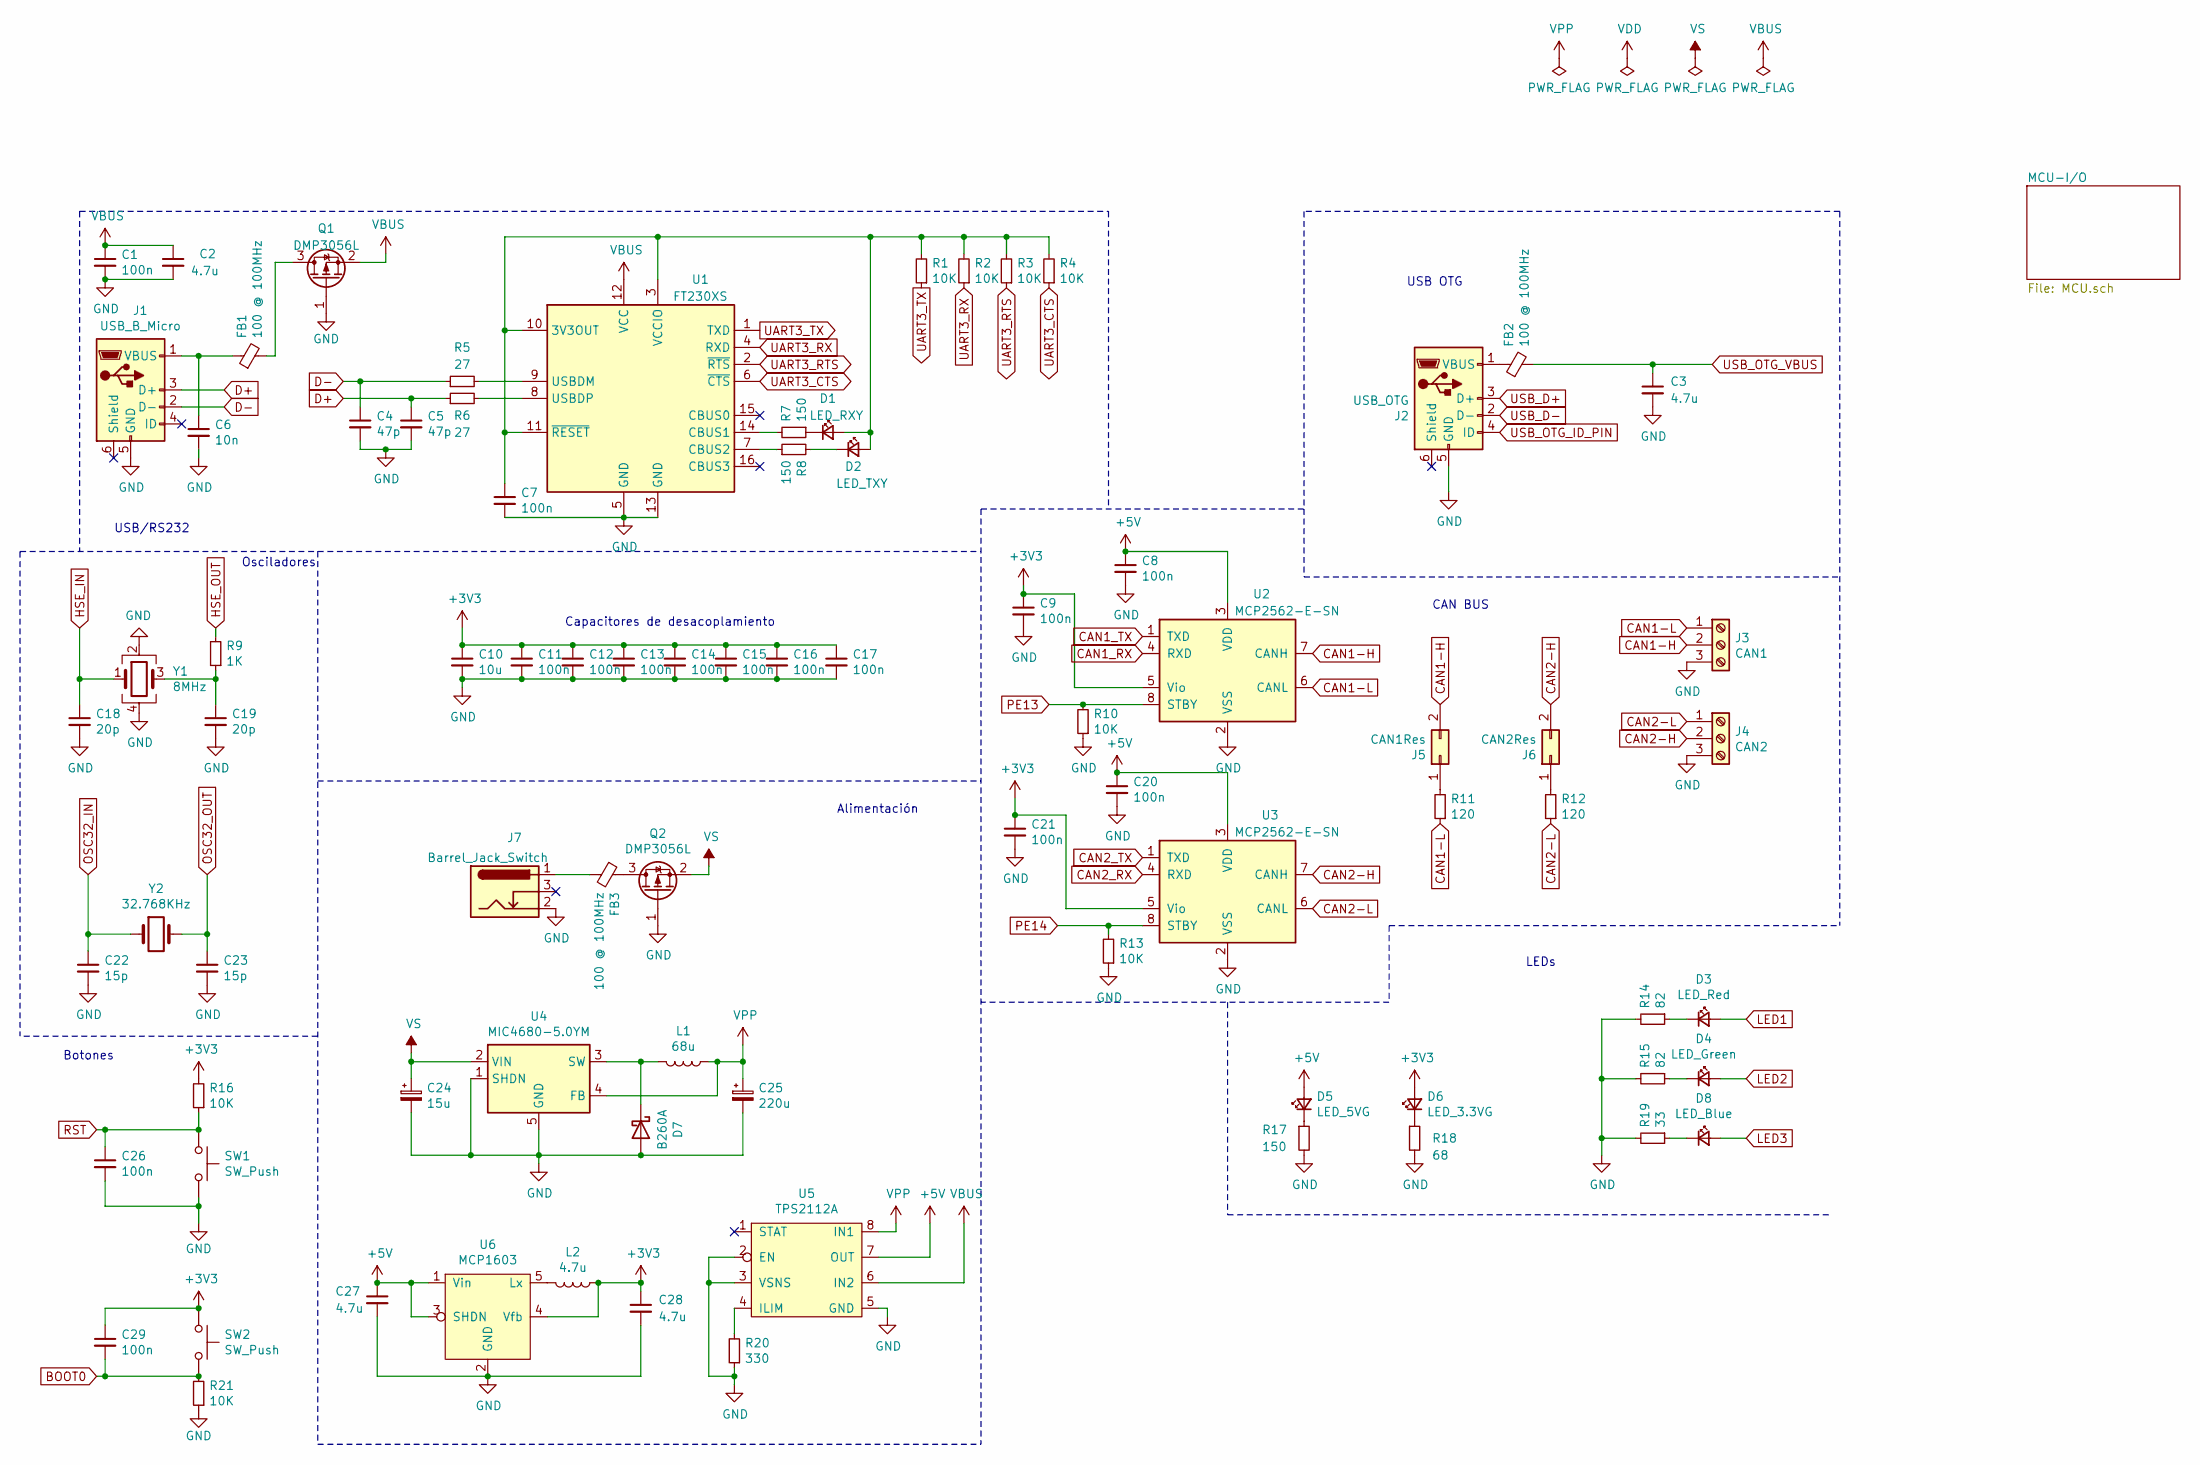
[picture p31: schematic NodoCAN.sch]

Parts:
C1, C7, C8, C9, C20, C21, C26, C29: 100n; C_0603_1608Metric
C2, C3, C27, C28: 4.7u; C_0805_2012Metric
C4, C5: 47p; C_0603_1608Metric
C6: 10n; C_0603_1608Metric
C10: 10u; C_0603_1608Metric
C11, C12, C13, C14, C15, C16, C17: 100n; C_0402_1005Metric
C18, C19: 20p; C_0402_1005Metric
C22, C23: 15p; C_0402_1005Metric
C24: 15u; CP_Elec_5x5.3
C25: 220u; CP_Elec_6.3x9.9
D1: LED_RXY; LED_0805_2012Metric
D2: LED_TXY; LED_0805_2012Metric
D3: LED_Red; LED_PLCC-2
D4: LED_Green; LED_PLCC-2
D5: LED_5VG; LED_0805_2012Metric
D6: LED_3.3VG; LED_0805_2012Metric
D7: B260A; D_SMA
D8: LED_Blue; LED_PLCC-2
FB1, FB2, FB3: 100 @ 100MHz; L_0805_2012Metric
J1: USB_B_Micro; USB_Micro-B_GCT_USB3076-30-A
J2: USB_OTG; USB_Micro-B_GCT_USB3076-30-A
J3: CAN1; TerminalBlock_Phoenix_MKDS-1,5-3-5.08_1x03_P5.08mm_Horizont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
J4: CAN2; TerminalBlock_Phoenix_MKDS-1,5-3-5.08_1x03_P5.08mm_Horizont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
J5: CAN1Res; PinHeader_2x01_P2.54mm_Vertical
J6: CAN2Res; PinHeader_2x01_P2.54mm_Vertical
J7: Barrel_Jack_Switch; BarrelJack_Horizontal
L1: 68u; UPB2
L2: 4.7u; L_1210_3225Metric
Q1, Q2: DMP3056L; SOT-23
R1, R2, R3, R4, R10, R13, R16, R21: 10K; R_0603_1608Metric
R5, R6: 27; R_0402_1005Metric
R7, R8, R17: 150; R_0805_2012Metric
R9: 1K; R_0402_1005Metric
R11, R12: 120; R_0805_2012Metric
R14, R15: 82; R_0805_2012Metric
R18: 68; R_0805_2012Metric
R19: 33; R_0805_2012Metric
R20: 330; R_1206_3216Metric
SW1, SW2: SW_Push; SW_Push_1P1T_NO_6x6mm_H9.5mm
U1: FT230XS; SSOP-16_3.9x4.9mm_P0.635mm
U2, U3: MCP2562-E-SN; SOIC-8_3.9x4.9mm_P1.27mm
U4: MIC4680-5.0YM; SOIC-8_3.9x4.9mm_P1.27mm
U5: TPS2112A; TSSOP-8_4.4x3mm_P0.65mm
U6: MCP1603; TSOT-23-5
Y1: 8MHz; Crystal_SMD_Abracon_ABM3B-4Pin_5.0x3.2mm
Y2: 32.768KHz; Crystal_SMD_2012-2Pin_2.0x1.2mm

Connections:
+3V3: C9.1, C10.1, C11.1, C12.1, C13.1, C14.1, C15.1, C16.1, C17.1, C21.1, C28.1, C29.1, D6.2 (A), L2.1, R16.2, SW2.1, U2.5 (Vio), U3.5 (Vio), U6.4 (Vfb); also elsewhere on the board
+5V: C8.1, C20.1, C27.1, D5.2 (A), U2.3 (VDD), U3.3 (VDD), U5.7 (OUT), U6.1 (Vin), U6.3 (SHDN); also elsewhere on the board
BOOT0: C29.2, R21.2, SW2.2; also elsewhere on the board
CAN1-H: J3.2, J5.2, U2.7 (CANH)
CAN1-L: J3.1, R11.1, U2.6 (CANL)
CAN1_RX: U2.4 (RXD); also elsewhere on the board
CAN1_TX: U2.1 (TXD); also elsewhere on the board
CAN2-H: J4.2, J6.2, U3.7 (CANH)
CAN2-L: J4.1, R12.1, U3.6 (CANL)
CAN2_RX: U3.4 (RXD); also elsewhere on the board
CAN2_TX: U3.1 (TXD); also elsewhere on the board
D+: C5.1, J1.3 (D+), R6.1
D-: C4.1, J1.2 (D-), R5.1
GND: C1.2, C2.2, C3.2, C4.2, C5.2, C6.2, C7.2, C8.2, C9.2, C10.2, C11.2, C12.2, C13.2, C14.2, C15.2, C16.2, C17.2, C18.2, C19.2, C20.2, C21.2, C22.2, C23.2, C24.2, C25.2, C26.2, C27.2, C28.2, D7.2 (A), J1.5 (GND), J2.5 (GND), J3.3, J4.3, J7.2, Q1.1 (G), Q2.1 (G), R10.1, R13.1, R14.2, R15.2, R17.2, R18.2, R19.2, R20.1, R21.1, SW1.2, U1.5 (GND), U1.13 (GND), U2.2 (VSS), U3.2 (VSS), U4.1 (SHDN), U4.5 (GND), U4.6 (GND), U4.7 (GND), U4.8 (GND), U5.2 (EN), U5.3 (VSNS), U5.5 (GND), U6.2 (GND), Y1.2, Y1.4; also elsewhere on the board
HSE_IN: C18.1, Y1.1; also elsewhere on the board
HSE_OUT: R9.2; also elsewhere on the board
LED1: D3.2 (A); also elsewhere on the board
LED2: D4.2 (A); also elsewhere on the board
LED3: D8.2 (A); also elsewhere on the board
unnamed: C6.1, FB1.1, J1.1 (VBUS)
unnamed: C7.1, D1.2 (A), D2.2 (A), R1.2, R2.2, R3.2, R4.2, U1.3 (VCCIO), U1.10 (3V3OUT), U1.11 (~RESET)
unnamed: C19.1, R9.1, Y1.3
unnamed: D1.1 (K), R7.1
unnamed: D2.1 (K), R8.2
unnamed: D3.1 (K), R14.1
unnamed: D4.1 (K), R15.1
unnamed: D5.1 (K), R17.1
unnamed: D6.1 (K), R18.1
unnamed: D7.1 (K), L1.2, U4.3 (SW)
unnamed: D8.1 (K), R19.1
unnamed: FB1.2, Q1.3 (D)
unnamed: FB2.1, J2.1 (VBUS)
unnamed: FB3.1, Q2.3 (D)
unnamed: FB3.2, J7.1
unnamed: J5.1, R11.2
unnamed: J6.1, R12.2
unnamed: L2.2, U6.5 (Lx)
unnamed: R5.2, U1.9 (USBDM)
unnamed: R6.2, U1.8 (USBDP)
unnamed: R7.2, U1.14 (CBUS1)
unnamed: R8.1, U1.7 (CBUS2)
unnamed: R20.2, U5.4 (ILIM)
OSC32_IN: C22.1, Y2.1; also elsewhere on the board
OSC32_OUT: C23.1, Y2.2; also elsewhere on the board
PE13: R10.2, U2.8 (STBY); also elsewhere on the board
PE14: R13.2, U3.8 (STBY); also elsewhere on the board
RST: C26.1, R16.1, SW1.1; also elsewhere on the board
UART3_CTS: R4.1, U1.6 (~CTS); also elsewhere on the board
UART3_RTS: R3.1, U1.2 (~RTS); also elsewhere on the board
UART3_RX: R2.1, U1.4 (RXD); also elsewhere on the board
UART3_TX: R1.1, U1.1 (TXD); also elsewhere on the board
USB_D+: J2.3 (D+); also elsewhere on the board
USB_D-: J2.2 (D-); also elsewhere on the board
USB_OTG_ID_PIN: J2.4 (ID); also elsewhere on the board
USB_OTG_VBUS: C3.1, FB2.2; also elsewhere on the board
VBUS: C1.1, C2.1, Q1.2 (S), U1.12 (VCC), U5.6 (IN2); also elsewhere on the board
VPP: C25.1, L1.1, U4.4 (FB), U5.8 (IN1)
VS: C24.1, Q2.2 (S), U4.2 (VIN); also elsewhere on the board

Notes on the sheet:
CAN BUS
USB OTG
Alimentación
Capacitores de desacoplamiento
LEDs
Botones
Osciladores
USB/RS232

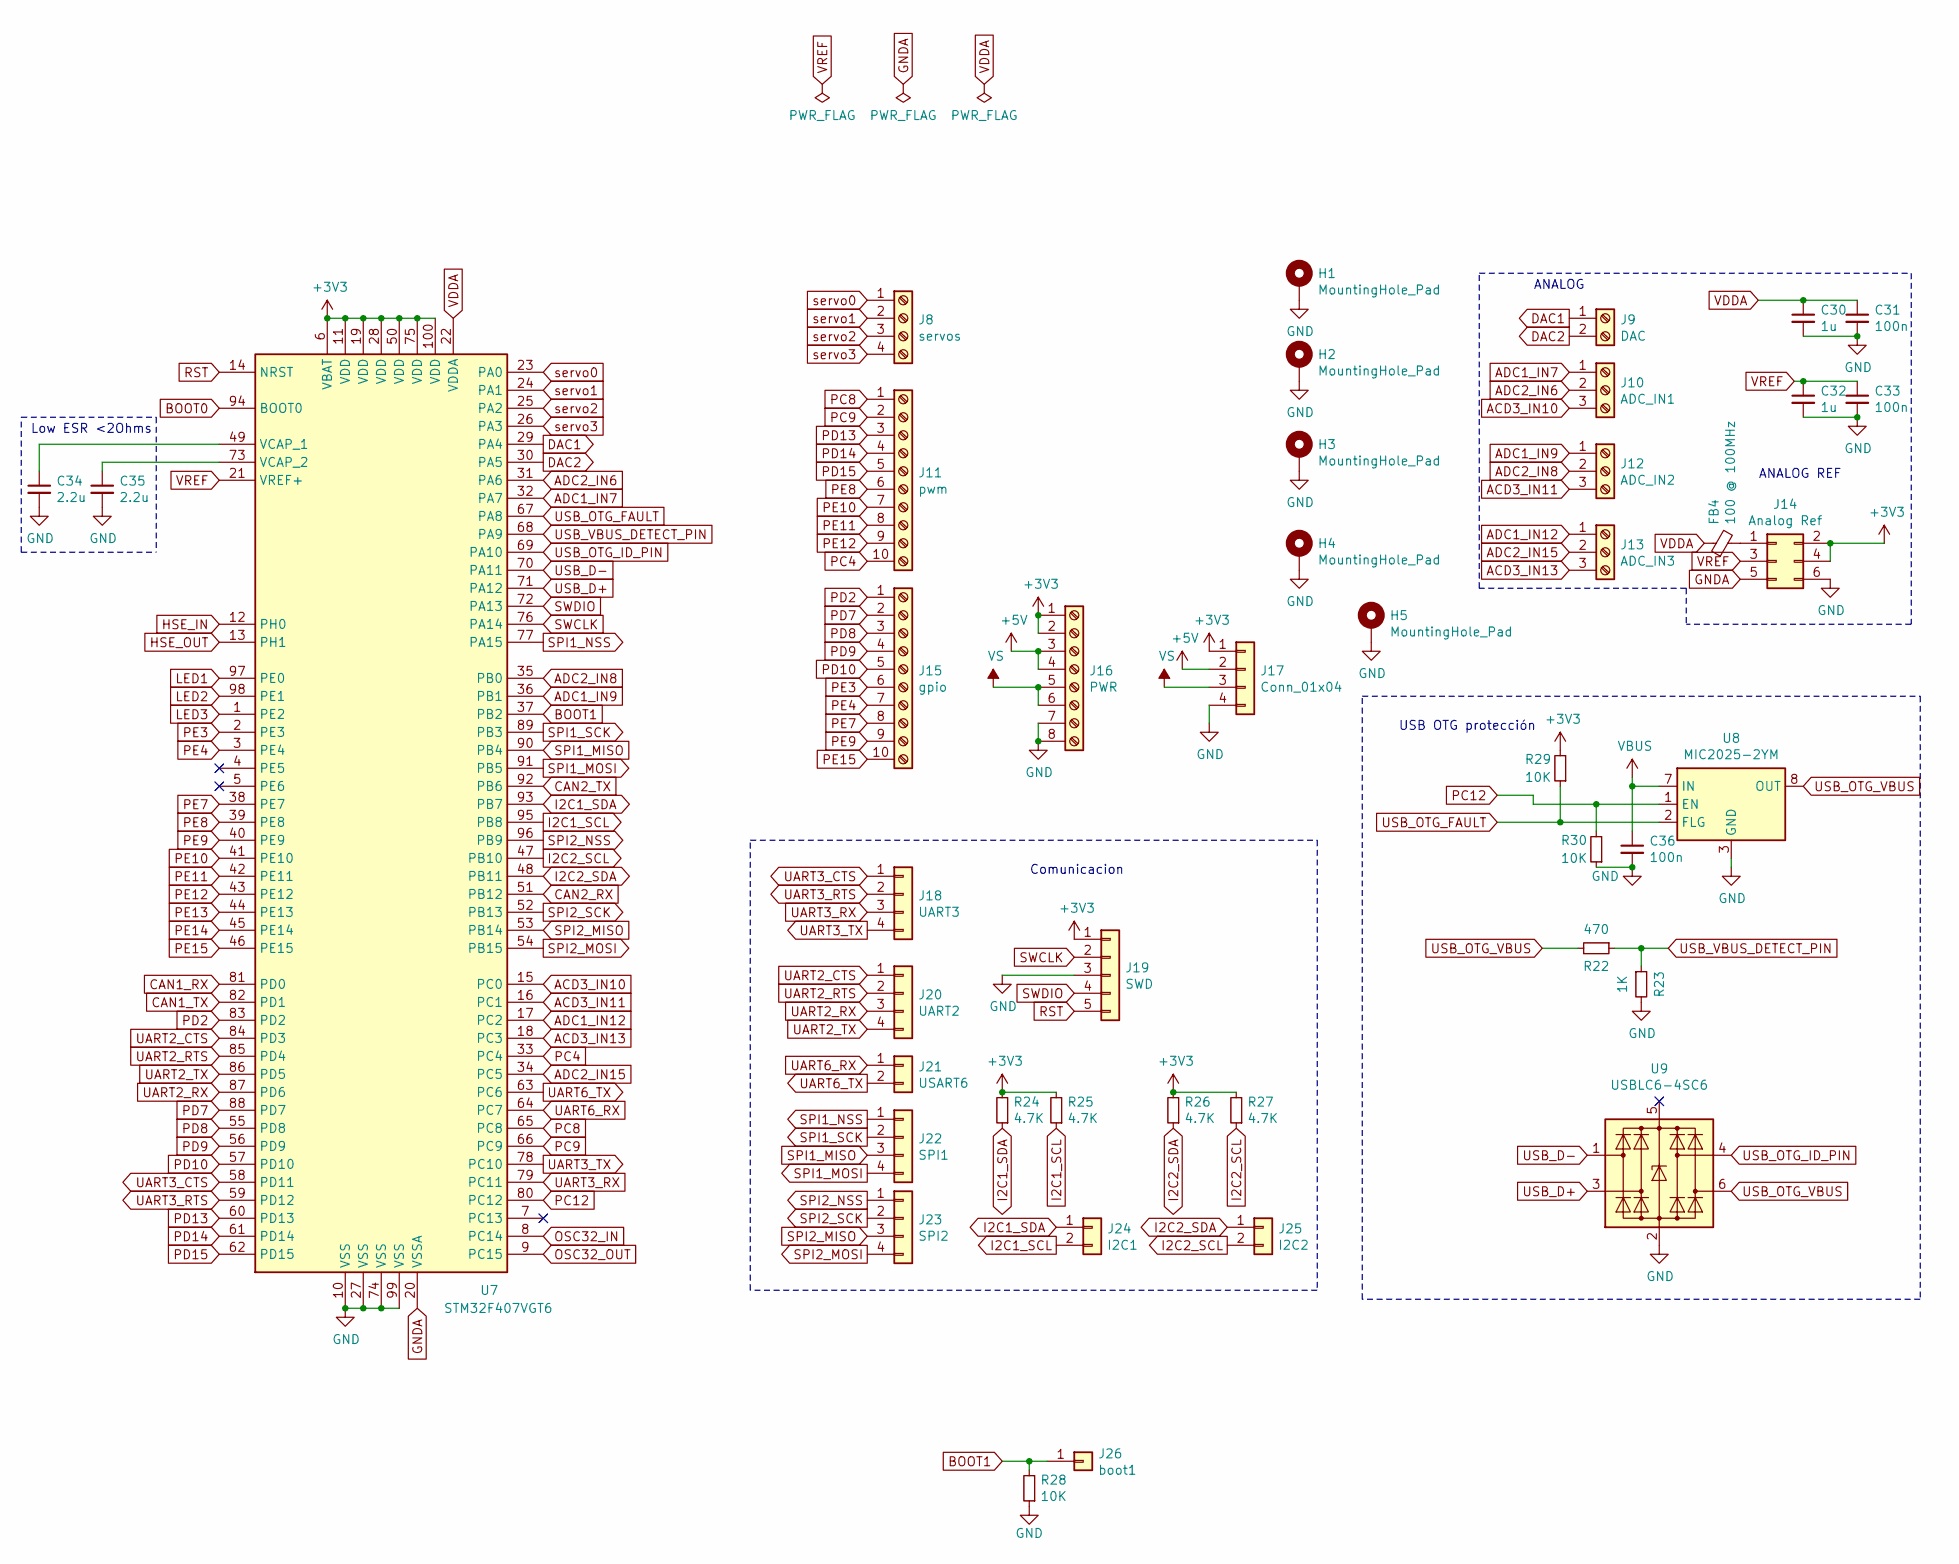
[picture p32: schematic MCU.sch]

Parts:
C30, C32: 1u; C_0402_1005Metric
C31, C33: 100n; C_0402_1005Metric
C34, C35: 2.2u; C_0805_2012Metric
C36: 100n; C_0603_1608Metric
FB4: 100 @ 100MHz; L_0805_2012Metric
H1, H2, H3, H4, H5: MountingHole_Pad; MountingHole_4.3mm_M4_Pad_Via
J8: servos; TerminalBlock_Phoenix_MKDS-1,5-4-5.08_1x04_P5.08mm_Horizont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
J9: DAC; TerminalBlock_Phoenix_MKDS-1,5-2-5.08_1x02_P5.08mm_Horizont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
J10: ADC_IN1; TerminalBlock_Phoenix_MKDS-1,5-3-5.08_1x03_P5.08mm_Horizont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
J11: pwm; TerminalBlock_Phoenix_MKDS-1,5-10-5.08_1x10_P5.08mm_Horizon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
J12: ADC_IN2; TerminalBlock_Phoenix_MKDS-1,5-3-5.08_1x03_P5.08mm_Horizont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
J13: ADC_IN3; TerminalBlock_Phoenix_MKDS-1,5-3-5.08_1x03_P5.08mm_Horizont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
J14: Analog Ref; PinHeader_2x03_P2.54mm_Vertical
J15: gpio; TerminalBlock_Phoenix_MKDS-1,5-10-5.08_1x10_P5.08mm_Horizon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
J16: PWR; TerminalBlock_Phoenix_MKDS-1,5-8-5.08_1x08_P5.08mm_Horizont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
J17: Conn_01x04; PinHeader_1x04_P2.54mm_Vertical
J18: UART3; PinHeader_1x04_P2.54mm_Vertical
J19: SWD; PinHeader_1x05_P2.54mm_Vertical
J20: UART2; PinHeader_1x04_P2.54mm_Vertical
J21: USART6; PinHeader_1x02_P2.54mm_Vertical
J22: SPI1; PinHeader_1x04_P2.54mm_Vertical
J23: SPI2; PinHeader_1x04_P2.54mm_Vertical
J24: I2C1; PinHeader_1x02_P2.54mm_Vertical
J25: I2C2; PinHeader_1x02_P2.54mm_Vertical
J26: boot1; PinHeader_1x01_P2.54mm_Vertical
R22: 470; R_0805_2012Metric
R23: 1K; R_0805_2012Metric
R24, R25, R26, R27: 4.7K; R_0402_1005Metric
R28, R29, R30: 10K; R_0603_1608Metric
U7: STM32F407VGT6; LQFP-100_14x14mm_P0.5mm
U8: MIC2025-2YM; SOIC-8_3.9x4.9mm_P1.27mm
U9: USBLC6-4SC6; SOT-23-6

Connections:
+3V3: J14.2, J14.4, J16.1, J16.2, J17.1, J19.1, R24.2, R25.2, R26.2, R27.2, R29.2, U7.6 (VBAT), U7.11 (VDD), U7.19 (VDD), U7.28 (VDD), U7.50 (VDD), U7.75 (VDD), U7.100 (VDD); also elsewhere on the board
+5V: J16.3, J16.4, J17.2; also elsewhere on the board
ACD3_IN10: J10.3, U7.15 (PC0)
ACD3_IN11: J12.3, U7.16 (PC1)
ACD3_IN13: J13.3, U7.18 (PC3)
ADC1_IN7: J10.1, U7.32 (PA7)
ADC1_IN9: J12.1, U7.36 (PB1)
ADC1_IN12: J13.1, U7.17 (PC2)
ADC2_IN6: J10.2, U7.31 (PA6)
ADC2_IN8: J12.2, U7.35 (PB0)
ADC2_IN15: J13.2, U7.34 (PC5)
BOOT0: U7.94 (BOOT0); also elsewhere on the board
BOOT1: J26.1, R28.2, U7.37 (PB2)
CAN1_RX: U7.81 (PD0); also elsewhere on the board
CAN1_TX: U7.82 (PD1); also elsewhere on the board
CAN2_RX: U7.51 (PB12); also elsewhere on the board
CAN2_TX: U7.92 (PB6); also elsewhere on the board
DAC1: J9.1, U7.29 (PA4)
DAC2: J9.2, U7.30 (PA5)
GND: C30.2, C31.2, C32.2, C33.2, C34.2, C35.2, C36.2, H1.1, H2.1, H3.1, H4.1, H5.1, J14.6, J16.7, J16.8, J17.4, J19.3, R23.2, R28.1, R30.1, U7.10 (VSS), U7.27 (VSS), U7.74 (VSS), U7.99 (VSS), U8.3 (GND), U9.2 (GND); also elsewhere on the board
GNDA: J14.5, U7.20 (VSSA)
HSE_IN: U7.12 (PH0); also elsewhere on the board
HSE_OUT: U7.13 (PH1); also elsewhere on the board
I2C1_SCL: J24.2, R25.1, U7.95 (PB8)
I2C1_SDA: J24.1, R24.1, U7.93 (PB7)
I2C2_SCL: J25.2, R27.1, U7.47 (PB10)
I2C2_SDA: J25.1, R26.1, U7.48 (PB11)
LED1: U7.97 (PE0); also elsewhere on the board
LED2: U7.98 (PE1); also elsewhere on the board
LED3: U7.1 (PE2); also elsewhere on the board
unnamed: C34.1, U7.49 (VCAP_1)
unnamed: C35.1, U7.73 (VCAP_2)
unnamed: FB4.2, J14.1
OSC32_IN: U7.8 (PC14); also elsewhere on the board
OSC32_OUT: U7.9 (PC15); also elsewhere on the board
PC4: J11.10, U7.33 (PC4)
PC8: J11.1, U7.65 (PC8)
PC9: J11.2, U7.66 (PC9)
PC12: R30.2, U7.80 (PC12), U8.1 (EN)
PD2: J15.1, U7.83 (PD2)
PD7: J15.2, U7.88 (PD7)
PD8: J15.3, U7.55 (PD8)
PD9: J15.4, U7.56 (PD9)
PD10: J15.5, U7.57 (PD10)
PD13: J11.3, U7.60 (PD13)
PD14: J11.4, U7.61 (PD14)
PD15: J11.5, U7.62 (PD15)
PE3: J15.6, U7.2 (PE3)
PE4: J15.7, U7.3 (PE4)
PE7: J15.8, U7.38 (PE7)
PE8: J11.6, U7.39 (PE8)
PE9: J15.9, U7.40 (PE9)
PE10: J11.7, U7.41 (PE10)
PE11: J11.8, U7.42 (PE11)
PE12: J11.9, U7.43 (PE12)
PE13: U7.44 (PE13); also elsewhere on the board
PE14: U7.45 (PE14); also elsewhere on the board
PE15: J15.10, U7.46 (PE15)
RST: J19.5, U7.14 (NRST); also elsewhere on the board
SPI1_MISO: J22.3, U7.90 (PB4)
SPI1_MOSI: J22.4, U7.91 (PB5)
SPI1_NSS: J22.1, U7.77 (PA15)
SPI1_SCK: J22.2, U7.89 (PB3)
SPI2_MISO: J23.3, U7.53 (PB14)
SPI2_MOSI: J23.4, U7.54 (PB15)
SPI2_NSS: J23.1, U7.96 (PB9)
SPI2_SCK: J23.2, U7.52 (PB13)
SWCLK: J19.2, U7.76 (PA14)
SWDIO: J19.4, U7.72 (PA13)
UART2_CTS: J20.1, U7.84 (PD3)
UART2_RTS: J20.2, U7.85 (PD4)
UART2_RX: J20.3, U7.87 (PD6)
UART2_TX: J20.4, U7.86 (PD5)
UART3_CTS: J18.1, U7.58 (PD11); also elsewhere on the board
UART3_RTS: J18.2, U7.59 (PD12); also elsewhere on the board
UART3_RX: J18.3, U7.79 (PC11); also elsewhere on the board
UART3_TX: J18.4, U7.78 (PC10); also elsewhere on the board
UART6_RX: J21.1, U7.64 (PC7)
UART6_TX: J21.2, U7.63 (PC6)
USB_D+: U7.71 (PA12), U9.3 (I/O2); also elsewhere on the board
USB_D-: U7.70 (PA11), U9.1 (I/O1); also elsewhere on the board
USB_OTG_FAULT: R29.1, U7.67 (PA8), U8.2 (FLG)
USB_OTG_ID_PIN: U7.69 (PA10), U9.4 (I/O3); also elsewhere on the board
USB_OTG_VBUS: R22.2, U8.6 (OUT), U8.8 (OUT), U9.6 (I/O4); also elsewhere on the board
USB_VBUS_DETECT_PIN: R22.1, R23.1, U7.68 (PA9)
VBUS: C36.1, U8.7 (IN); also elsewhere on the board
VDDA: C30.1, C31.1, FB4.1, U7.22 (VDDA)
VREF: C32.1, C33.1, J14.3, U7.21 (VREF+)
VS: J16.5, J16.6, J17.3; also elsewhere on the board
servo0: J8.1, U7.23 (PA0)
servo1: J8.2, U7.24 (PA1)
servo2: J8.3, U7.25 (PA2)
servo3: J8.4, U7.26 (PA3)

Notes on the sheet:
ANALOG
ANALOG REF
Comunicacion
Low ESR <2Ohms
USB OTG protección

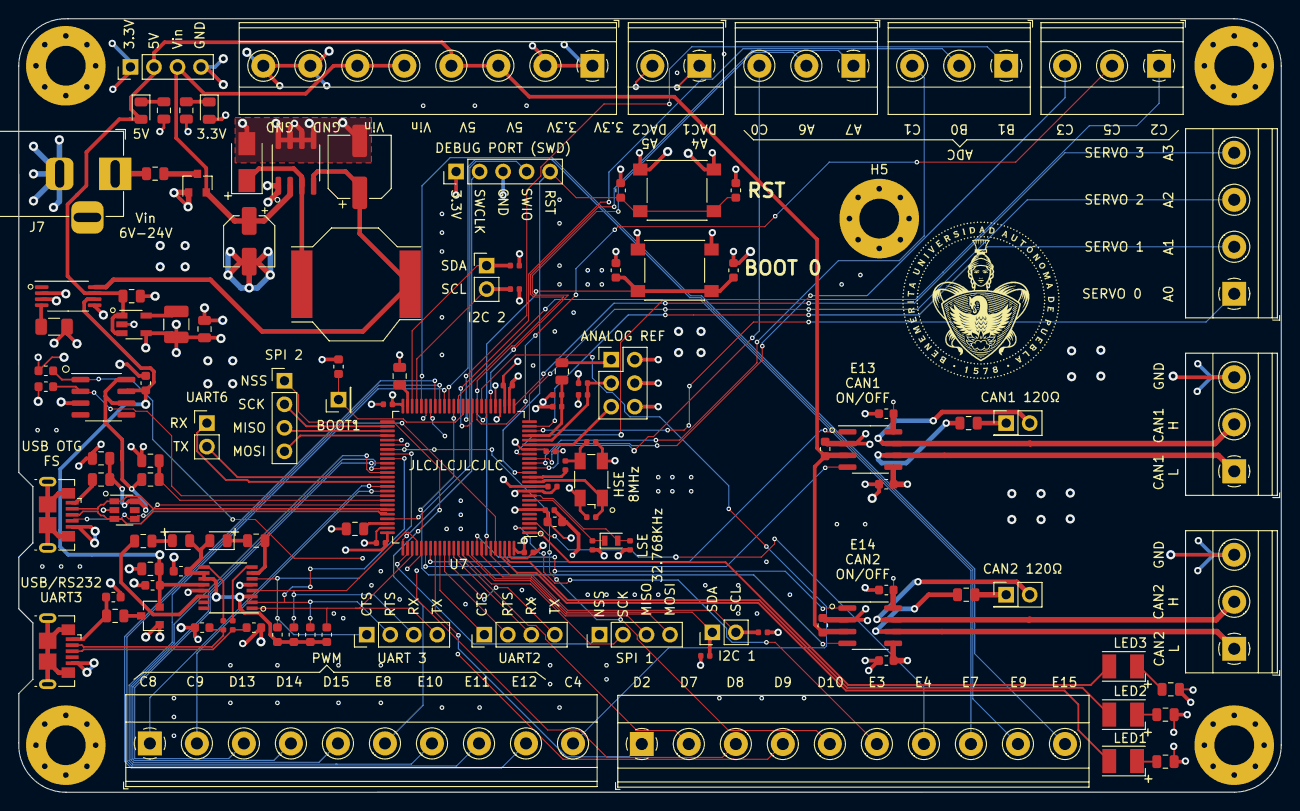
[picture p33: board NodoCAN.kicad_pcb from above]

Board: 4 copper layers, 136.4 x 83.6 mm, 126 parts (0 on the bottom side), 123 nets.

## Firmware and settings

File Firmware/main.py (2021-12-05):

from pyb import Pin     #MicroPython library to control the GPIO
from pyb import Timer   #MicroPython library to control the Timers
from pyb import UART    #MicroPython library to control the UART

#encoder's pulses per revolution
ppr = 1056

#UART port configuration
buff_length=11      #length of the incoming reference signal
PueSer = UART(3)    #create a UART object for UART 3 that is connected to USB/UART converter
PueSer.init(115200,bits=8,parity=None,stop=1,timeout=0,rxbuf=buff_length)    #Initialize the UART port setting the buffer size and speed

#Encoder pins configurarion
pin_a = Pin('A0', Pin.AF_PP, pull=Pin.PULL_NONE, af=Pin.AF1_TIM2)   #create a pin objet without pull up or pull down and with the alternate funtion 1 for the selected timmer
pin_b = Pin('A1', Pin.AF_PP, pull=Pin.PULL_NONE, af=Pin.AF1_TIM2)

pin_c = Pin('E9', Pin.AF_PP, pull=Pin.PULL_NONE, af=Pin.AF1_TIM1)
pin_d = Pin('E11', Pin.AF_PP, pull=Pin.PULL_NONE, af=Pin.AF1_TIM1)

pin_e = Pin('D12', Pin.AF_PP, pull=Pin.PULL_NONE, af=Pin.AF2_TIM4)
pin_f = Pin('D13', Pin.AF_PP, pull=Pin.PULL_NONE, af=Pin.AF2_TIM4)

#encoder timer configuration
enc_timer1 = Timer(2, prescaler=0, period=ppr)  #creates a timer object with the number of pulses in the encoder
enc_timer2 = Timer(1, prescaler=0, period=ppr)
enc_timer3 = Timer(4, prescaler=0, period=ppr)

enc_channel1 = enc_timer1.channel(1, Timer.ENC_AB)  #creates an object of a timer chanel and set the mode to encoder AB
enc_channel2 = enc_timer2.channel(1, Timer.ENC_AB)
enc_channel3 = enc_timer3.channel(1, Timer.ENC_AB)

#Pins used to measure the system's perfomrance
debug = Pin(Pin.cpu.D10, Pin.OUT_PP)    #creates a pin object set as output
debug_1 = Pin(Pin.cpu.D11, Pin.OUT_PP)
debug_2 = Pin(Pin.cpu.D8, Pin.OUT_PP)
debug_3 = Pin(Pin.cpu.D9, Pin.OUT_PP)
debug_4 = Pin(Pin.cpu.B14, Pin.OUT_PP)
debug_5 = Pin(Pin.cpu.B15, Pin.OUT_PP)
debug.off()     #sets the pin to low
debug_1.off()
debug_2.off()
debug_3.off()
debug_4.off()
debug_5.off()

#Pins to control the direction of the motors
D1 = Pin(Pin.cpu.C4, Pin.OUT_PP)
Iz1 = Pin(Pin.cpu.C5, Pin.OUT_PP)
D1.off()
Iz1.off()

D3 = Pin(Pin.cpu.E4, Pin.OUT_PP)
Iz3 = Pin(Pin.cpu.E3, Pin.OUT_PP)
D3.off()
Iz3.off()

D2 = Pin(Pin.cpu.C1, Pin.OUT_PP)
Iz2 = Pin(Pin.cpu.C0, Pin.OUT_PP)
D2.off()
Iz2.off()

#PWM pins to control the speed of the motor
En1 = Pin('A3') #creates an uninitialized pin object
tim1 = Timer(5, freq=900)   #creates a timer object initialized to 900Hz
ch1 = tim1.channel(4, Timer.PWM, pin=En1)   #creates a timer channel object in PWM mode
ch1.pulse_width_percent(0)  #turns off the pwm pin

En3 = Pin('E6')
tim3 = Timer(9, freq=900)
ch3 = tim3.channel(2, Timer.PWM, pin=En3)
ch3.pulse_width_percent(0)

En2 = Pin('B1')
tim2 = Timer(3, freq=900)
ch2 = tim2.channel(4, Timer.PWM, pin=En2)
ch2.pulse_width_percent(0)

#ESO constants
l0=100000000
l1=6000000
l2=110000
l3=600

#initialization of variables
tik=0   #flag to control the sampling rate
clutch=0    #variable to count the first iterations of the the program
#fag=0   
Vsource = 12        #Voltage source that powers the H-Bridge
Vmax = 9            #maximum voltage level for the motors
pwm_max = 100       #maximum level for the PWM with
initial_angle = 90  #Initial position for the motors
angle_shift = 90    #angle shifting to prevent 0 crossing
send_flag = 4       #flag to control the data sending

#initialization of contorl variables
hatx11=0
hatx21=0
z11=0
z21=0
hatx1old1=0
hatx2old1=0
z1old1=0
z2old1=0
xold1=0
v1=0,0

hatx12=0
hatx22=0
z12=0
z22=0
hatx1old2=0
hatx2old2=0
z1old2=0
z2old2=0
xold2=0
v2=0,0

hatx13=0
hatx23=0
z13=0
z23=0
hatx1old3=0
hatx2old3=0
z1old3=0
z2old3=0
xold3=0
v3=0,0

#finction to map a value in a different range
def pymap(value, istart, istop, ostart, ostop):
    return ostart + (ostop - ostart) * ((value - istart) / (istop - istart))

#function that raises a flag if the samplig rate timmer creates an interruption
def f(t):
    global tik
    tik=1

#funtion that formats the motor position
def readpos(x):
    position=pymap(x, 0, ppr, 0, 360)
    return position

#CONTROL LAW
def control(x,y,hatx,z):
    #control constants
    k1 = 90
    k2 = 20
    R=5.1
    Jm=0.050
    r=48
    Ka=0.010
    #calculate the error
    e = x-y
    eabs=abs(e)
    #calculate he control law
    if eabs < 1:
        u = 0               #if the error is small the control signal is 0
    else:
        u = -k1*(e)-k2*hatx #calculate the control signal
        u = u-z             #compensate the disturbances
    v = u*((Jm*r*R)/Ka)     #convert the control signal to a voltage signal
    #check if the voltage signal is within the voltage limits
    if v > Vmax:
        v = Vmax
    elif v < -Vmax:
        v = -Vmax        
    return v,u  #return voltage and control signals

# def controlTEST(x,y,hatx,z,k1,k2):
#     #constantes control
#     # k1 = 50
#     # k2 = 20
#     R=5.1
#     Jm=0.050
#     r=48
#     Ka=0.010
#     e = x-y
#     eabs=abs(e)
#     if eabs < 1:
#         u = 0
#     else:
#         u = -k1*(e)-k2*hatx
#         u = u-z
#     v = u*((Jm*r*R)/Ka)
#     if v > Vmax:
#         v = Vmax
#     elif v < -Vmax:
#         v = -Vmax        
#     return v,u

# functions to update the motors position and speed
def updateout1(vt1,Vsource):
    # motor 1
    # depending on the voltage value is the direction of the motor
    if vt1<0:
        D1.on()         #direction is updated
        Iz1.off()
    elif vt1>0:
        D1.off()
        Iz1.on()
    else:
        D1.off()
        Iz1.off()
    # the absolute value of the voltage is converted to a PWM width
    vt1 = abs(vt1)
    vt1 = pymap(vt1,0,Vsource,0,pwm_max)
    ch1.pulse_width_percent(vt1)    #speed is updated
    
def updateout2(vt2,Vsource):
    # motor2
    if vt2<0:
        D2.on()
        Iz2.off()
    elif vt2>0:
        D2.off()
        Iz2.on()
    else:
        D2.off()
        Iz2.off()
    vt2 = abs(vt2)
    vt2 = pymap(vt2,0,Vsource,0,pwm_max)
    ch2.pulse_width_percent(vt2)
        
def updateout3(vt3,Vsource):
    # motor 3
    if vt3<0:
        D3.on()
        Iz3.off()
    elif vt3>0:
        D3.off()
        Iz3.on()
    else:
        D3.off()
        Iz3.off()
    vt3 = abs(vt3)
    vt3 = pymap(vt3,0,Vsource,0,pwm_max)
    ch3.pulse_width_percent(vt3)

# function to make the output string always 3 characters long
def format_out(x):
    x = int(x)
    if x < 100:
        if x < 10:
            x = str(x)
            x = '00'+x
        else:
            x = str(x)
            x = '0'+str(x)
    else:
        x = str(x)
    return x

# pre-calculate variables
pwm_vmax = int(pymap(Vmax,0,Vsource,0,pwm_max))         #maximun value the PWM width can get to reach the maximum motor voltage
initial_pos = int(pymap(initial_angle + angle_shift, 0, 360, 0, ppr))   #calulate the initial position to initialize the enceder timer

# samplig rate configuration
t=0.0025    #sampling rate in seconds
tim7 = Timer(7, freq=400, callback=f)   #create at imer object initialized to create a interruption callback in 400Hz

# initialize encoder's timers
enc_timer1.counter(initial_pos)
enc_timer2.counter(initial_pos)
enc_timer3.counter(initial_pos)

# Control Loop
while True:
    if tik==1:      #executes if the sampling rate timer has created an intruption
        tik=0       #lowers the interrupt flag
        debug.on()  #first aux pin set high to measure overall calculation time
        
        # Inputs
        debug_1.on()                #second aux pin set high to measure the motors position
        x1=enc_timer1.counter()     #reads motors actual position  
        x1=readpos(x1)              #formats the position
        x2=enc_timer2.counter()
        x2=readpos(x2)
        x3=enc_timer3.counter()
        x3=readpos(x3)
        debug_1.off()               #second aux pin set low to measure the motors position
        if clutch < 50:             #for the first 50 iteratiosn the reference is ecual to the measured position to alow the ESO to converge
            y1=x1
            y2=x2
            y3=x3
            clutch=clutch+1
        
        # Calculate the ESOs
        # ESO1
        debug_2.on()        #third aux pin set high to measure the ESO calculation time
        hatx11 = hatx1old1 + t*(hatx2old1+l3*(xold1-hatx1old1))     #calulate estimated position
        hatx21 = hatx2old1 + t*(v1[1]+z1old1+l2*(xold1-hatx1old1))  #calulate estimated velocity
        z11 = z1old1 + t*(z2old1+l1*(xold1-hatx1old1))              #calulate estimated disturbance
        z21 = z2old1 + t*(l0*(xold1-hatx1old1))
        hatx1old1 = hatx11      #update last position
        hatx2old1 = hatx21      #update last velocity
        if z11 > 5000:      #limit estimated disturbance to avoid control loss
            z11 = 5000
        elif z11 < -5000:
            z11 = -5000
        z1old1 = z11        #update last disturbance
        z2old1 = z21
        xold1=x1            #update last measured position
        
        # ESO2
        hatx12 = hatx1old2 + t*(hatx2old2+l3*(xold2-hatx1old2))
        hatx22 = hatx2old2 + t*(v2[1]+z1old2+l2*(xold2-hatx1old2))
        z12 = z1old2 + t*(z2old2+l1*(xold2-hatx1old2))
        z22 = z2old2 + t*(l0*(xold2-hatx1old2))
        if z12 > 5000:
            z12 = 5000
        elif z12 < -5000:
            z12 = -5000
        hatx1old2 = hatx12
        hatx2old2 = hatx22
        z1old2 = z12
        z2old2 = z22
        xold2=x2
        
        # ESO3
        hatx13 = hatx1old3 + t*(hatx2old3+l3*(xold3-hatx1old3))
        hatx23 = hatx2old3 + t*(v3[1]+z1old3+l2*(xold3-hatx1old3))
        z13 = z1old3 + t*(z2old3+l1*(xold3-hatx1old3))
        z23 = z2old3 + t*(l0*(xold3-hatx1old3))
        if z13 > 5000:
            z13 = 5000
        elif z13 < -5000:
            z13 = -5000
        hatx1old3 = hatx13
        hatx2old3 = hatx23
        z1old3 = z13
        z2old3 = z23
        xold3=x3
        debug_2.off()       #third aux pin set low to measure the ESO calculation time
        
        # control calculation
        debug_3.on()        #fourth aux pin set high to measure the control law calculation time
        v1 = control(x1,y1,hatx21,z11)  #call the control calculation function for motor 1
        v2 = control(x2,y2,hatx22,z12)
        v3 = control(x3,y3,hatx23,z13)
        debug_3.off()       #fourth aux pin set low to measure the control law calculation time
        
        # Update output
        debug_4.on()        #fifth aux pin set high to measure the output updateing time
        updateout1(v1[0],Vsource)   #call update funtion for motor 1
        updateout2(v2[0],Vsource)
        updateout3(v3[0],Vsource)
        debug_4.off()       #fifth aux pin set low to measure the output updateing time
        debug.off()         #first aux pin set low to measure overall calculation time
        
        # serial communication
        if  PueSer.any() >= buff_length:        #check if there's a full menssage in the buffer
            debug_5.on()                        #sixth aux pin set high to measure the serial income communication time
            x = PueSer.read(buff_length)        #reads the UART buffer
            try:                                #"try" comand used to avoid program failure in case of misscomunication
                data= x.decode('ascii')         #decode the incomming message to a string format
                if data == 'setcurrentp':       #check if the recieved message is the set current position comand
                    enc_timer1.counter(initial_pos)     #re-initalize encoder timer position
                    enc_timer2.counter(initial_pos)
                    enc_timer3.counter(initial_pos)
                    y1 = initial_angle + angle_shift    #update reference position to initial position
                    y2 = initial_angle + angle_shift
                    y3 = initial_angle + angle_shift
                else:                           #update reference psition win message
                    y1 = int(data[0:3])         #tranform to integer the first 3 characters
                    y1 += angle_shift           #add the angle shift to avoid zero corssing
                    y2 = int(data[4:7])
                    y2 += angle_shift
                    y3 = int(data[8:])
                    y3 += angle_shift
            except:
                pass        #do not update the reference position if any error occurs
            debug_5.off()
# END of normal program uncoment the nex section to send back motor 3 position
        #     strtemp = format_out(x3)
        #     send_flag = 0
        # else:
        #     if send_flag <= 2:
        #         PueSer.write(strtemp[send_flag].encode('ascii'))
        #         send_flag = send_flag + 1
        #         debug_5.off()
        #     debug_5.on()
        #     x3=int(x3)
        #     if x3 < 100:
        #         x3 = str(x3)
        #         x3 = '0'+x3
        #     else:
        #         x3 = str(x3)
        #     debug_5.off()
# 
# 
# while True:
#     delay(2)
#     if  PueSer.any():
#         if PueSer.any()>=buff_length:
#             debug.on()
#             x = PueSer.read(buff_length)
#     #         print(x)
#             debug.off()
#             data= x.decode('ascii')
#             debug.on()
#             data = data.split("/")
#             debug.off()
#             x1=int(data[0])
#             x2=int(data[1])
#             x3=int(data[2])
#             debug.on()
#             PueSer.write(x)
#             debug.off()


#Start of new prgram

# while True:
#     if tik==1:
#         tik=0
#         debug.on()
        
#         #inputs
#         debug_1.on()
#         x1=enc_timer1.counter()
#         x1=readpos(x1)
#         debug_1.off()
#         x2=enc_timer2.counter()
#         x2=readpos(x2)
#         debug_1.on()
#         x3=enc_timer3.counter()
#         x3=readpos(x3)
#         debug_1.off()
#         if clutch < 50:
#             y1=x1
#             y2=x2
#             y3=x3
#             clutch=clutch+1
            
#         #OEE1
#         debug_2.on()
#         hatx11 = hatx1old1 + t*(hatx2old1+l3*(xold1-hatx1old1))
#         hatx21 = hatx2old1 + t*(v1[1]+z1old1+l2*(xold1-hatx1old1))
#         z11 = z1old1 + t*(z2old1+l1*(xold1-hatx1old1))
#         z21 = z2old1 + t*(l0*(xold1-hatx1old1))
#         hatx1old1 = hatx11
#         hatx2old1 = hatx21
#         if z11 > 5000:
#             z11 = 5000
#         elif z11 < -5000:
#             z11 = -5000
#         z1old1 = z11
#         z2old1 = z21
#         xold1=x1
#         debug_2.off()
        
#         #OEE2
#         hatx12 = hatx1old2 + t*(hatx2old2+l3*(xold2-hatx1old2))
#         hatx22 = hatx2old2 + t*(v2[1]+z1old2+l2*(xold2-hatx1old2))
#         z12 = z1old2 + t*(z2old2+l1*(xold2-hatx1old2))
#         z22 = z2old2 + t*(l0*(xold2-hatx1old2))
#         if z12 > 5000:
#             z12 = 5000
#         elif z12 < -5000:
#             z12 = -5000
#         hatx1old2 = hatx12
#         hatx2old2 = hatx22
#         z1old2 = z12
#         z2old2 = z22
#         xold2=x2
        
#         #OEE3
#         debug_2.on()
#         hatx13 = hatx1old3 + t*(hatx2old3+l3*(xold3-hatx1old3))
#         hatx23 = hatx2old3 + t*(v3[1]+z1old3+l2*(xold3-hatx1old3))
#         z13 = z1old3 + t*(z2old3+l1*(xold3-hatx1old3))
#         z23 = z2old3 + t*(l0*(xold3-hatx1old3))
#         if z13 > 5000:
#             z13 = 5000
#         elif z13 < -5000:
#             z13 = -5000
#         hatx1old3 = hatx13
#         hatx2old3 = hatx23
#         z1old3 = z13
#         z2old3 = z23
#         xold3=x3
#         debug_2.off()

#         #control
#         debug_3.on()
#         v1 = controlTEST(x1,y1,hatx21,z11,k1,k2)
#         debug_3.off()
#         v2 = controlTEST(x2,y2,hatx22,z12,k1,k2)
#         debug_3.on()
#         v3 = controlTEST(x3,y3,hatx23,z13,k1,k2)
#         debug_3.off()
        
#         #actualizar salida
#         debug_4.on()
#         updateout1(v1[0],x1,Vsource)
#         debug_4.off()
#         updateout2(v2[0],x2,Vsource)
#         debug_4.on()
#         updateout3(v3[0],x3,Vsource)
#         debug_4.off()
#         debug.off()
        
#         # comunicacion serial
#         if  PueSer.any() >= buff_length:
#             debug_5.on()
#             x = PueSer.read(buff_length)
#             try:
#                 data= x.decode('ascii')
#                 # print(data)
#                 if data == 'setcurrentp':
#                     enc_timer1.counter(initial_pos)
#                     enc_timer2.counter(initial_pos)
#                     enc_timer3.counter(initial_pos)
#                     y1 = initial_angle + angle_shift
#                     y2 = initial_angle + angle_shift
#                     y3 = initial_angle + angle_shift
#                     # print('position updated')
#                 else:
#                     y1 = int(data[0:3])
#                     y1 += angle_shift
#                     k1 = int(data[4:7])
#                     k2 = int(data[8:])
#             except:
#                 #print('error de com')
#                 pass
#             debug_5.off()
#             strtemp = format_out(x1)
#             send_flag = 0
#         else:
#             if send_flag <= 2:
#                 # debug_5.on()
#                 PueSer.write(strtemp[send_flag].encode('ascii'))
#                 send_flag = send_flag + 1
#                 # debug_5.off()
#             # PueSer.write(x)
#             #debug_5.on()
#             x1=int(x1)
#             if x1 < 100:
#                 x1 = str(x1)
#                 x1 = '0'+x1
#             else:
#                 x1 = str(x1)
#             # print(x1)

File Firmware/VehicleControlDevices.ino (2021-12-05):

/*
 *  2021 Ivan Canedo Farfan
 *  BUAP MIEL
*/

String inputString = "";         // a String to hold incoming data
String outString = "";
bool Flag = false;  // whether the string is complete
const int pot1 = A0;
const int pot2 = A1;
const int pot3 = A2;
const int rev = 2;
const int HB = 3;
const int STOP = 4;
const int aux = 9;
const int steerMax = 200;
const int pedalMax = 100;
const int throtleMin = 480;
const int throtleMax = 503;
const int brakeMin = 510;
const int brakeMax = 536;
int temp = 0;

void setup() {
  // initialize serial:
  Serial.begin(115200);
  // initialize pins
  pinMode(aux,OUTPUT);
  pinMode(rev,INPUT_PULLUP);
  pinMode(HB,INPUT_PULLUP);
  pinMode(STOP,INPUT_PULLUP);
  // reserve 200 bytes for the inputString:
  inputString.reserve(200);
  //analogReference(DEFAULT);
}

void loop() {
  if (Flag) {
    digitalWrite(aux, HIGH);
    // read devices states
    int pot1Value = analogRead(pot1);
    int pot2Value = analogRead(pot2);
    int pot3Value = analogRead(pot3);
    bool buttonState1 = digitalRead(rev);
    bool buttonState2 = digitalRead(HB);
    bool buttonState3 = digitalRead(STOP);
    if (buttonState3){
      buttonState3 = 0;
    }
    else{
      buttonState3 = 1;
    }
    // format steering wheel
    temp = map(pot1Value, 0, 1023, 0, steerMax);
    String Steer = String(temp);
    // format throtle pedal
    temp = map(pot2Value, throtleMin, throtleMax, 0, pedalMax);
    temp = AngleCheck(temp);
    String Throtle = String(temp);
    // format break pedal
    temp = map(pot3Value, brakeMin, brakeMax, 0, pedalMax);
    temp = AngleCheck(temp);
    String Break = String(temp);
    // format reverse selector
    String Rev = String(buttonState1);
    // fromat hand brake selector
    String hb = String(buttonState2);
    // fromat emergency stop button
    String st = String(buttonState3);
    // create output string
    outString = String(Steer + "/" + Throtle + "/" + Break + "/" + Rev + hb + st);
    // print output string
    Serial.print(outString);
    Serial.print("\n");
    digitalWrite(aux, LOW);
    // lower flag to wait for another request
    Flag = false;
  }
}

/*
  checcks if the values is between the boundaries
  input 'y' = true for steering wheel and false for pedals
*/
int AngleCheck(int x) {
  int result;
  if (x > pedalMax) {
    result = pedalMax;
  }
  else if (x < 0) {
    result = 0;
  }
  else {
    result = x;
  }
  return result;
  }

/*
  SerialEvent occurs whenever a new data comes in the hardware serial RX. This
  routine is run between each time loop() runs, so using delay inside loop can
  delay response. Multiple bytes of data may be available.
*/
void serialEvent() {
    char inChar = (char)Serial.read();
    if (inChar == '\n') {
      Flag = true;
    }
}
